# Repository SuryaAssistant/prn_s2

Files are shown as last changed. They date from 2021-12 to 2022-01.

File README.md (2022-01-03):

<!-- Title -->
<span align = "center">

# PRN
  <b>Bidirectional SMPS Inverter</b>

STM32 Code

September - December 2021

This repository is open to copy for Educational purpose only and not for commercial use

</span>
<!-- End of Title -->

## Warning
The code and OpenHantek software are produced in Linux OS computer. We recommend you to use or edit the code in Linux computer for compatibility purpose. Nevertheless, you still can use this repo in Windows computer with some configuration but not for OpenHantek.

## Brief Overview of The Repository
This repository is used to save and documenting the development of bidirectional SMPS inverter project. The project was took place in Instrumentation and Control Laboratory, Universitas Sebelas Maret.

## Prequerities
Yout need to have this software before use this repository
- STM32CubeIDE v1.6.1 or above. Link : https://www.st.com/en/development-tools/stm32cubeide.html
- OpenHantek6022 (Linux). Link : https://github.com/OpenHantek/OpenHantek6022
- Autodesk Eagle v9.3.0 or above (Linux or Windows). Link : https://www.autodesk.com/products/eagle/free-download

## How To Use (Linux)
From Terminal, clone this repository to your folder
```
git clone https://github.com/SuryaAssistant/prn_s2
```

Open STM32CubeIDE and then open project `prn_s2.ioc` in `stm32` folder.

The main code is saved in `stm32/Core/Src/main.c`.

## How To Use (Windows)
Download this repository by clicking green button in right-top of repository.

Extract the zip file and then move the `stm32` folder into <b>STM32CubeIDE workspace</b> in (usually) `C:\Users\{Your_Computer_Name}\STM32CubeIDE\{Your_Workspace_Name}\`.

## Clock Configuration
<span align="center">
  
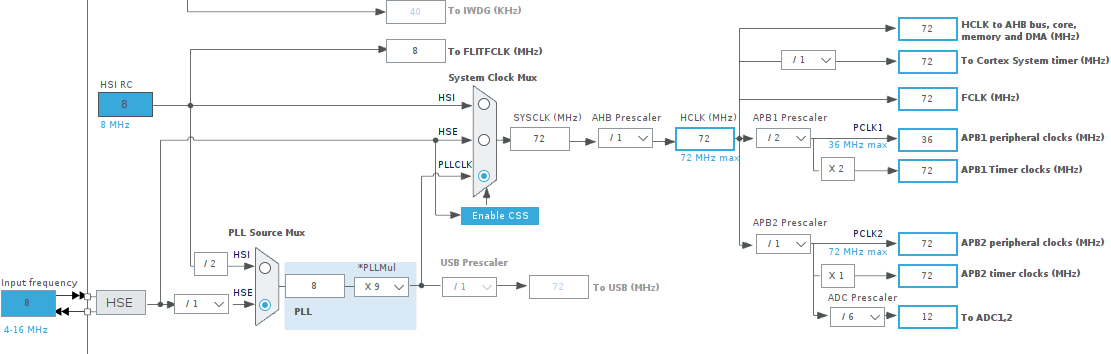
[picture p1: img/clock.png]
 
  
</span>

## Pinout
<span align="center">
  
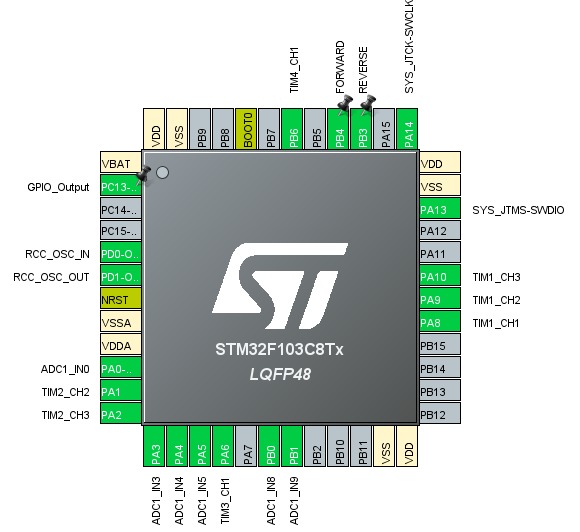
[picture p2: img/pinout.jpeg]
 
  
</span>

## Further Information
- Read the STM32CubeIDE timer and ADC configuration in https://github.com/SuryaAssistant/prn_s2/tree/main/tutorial
- Read SPWM specific configuration in https://github.com/SuryaAssistant/prn_s2/tree/main/spwm
- PCB schematic and board Design Documentation in https://github.com/SuryaAssistant/prn_s2/tree/main/pcb

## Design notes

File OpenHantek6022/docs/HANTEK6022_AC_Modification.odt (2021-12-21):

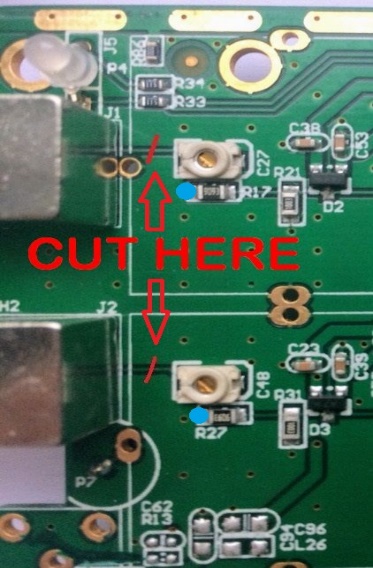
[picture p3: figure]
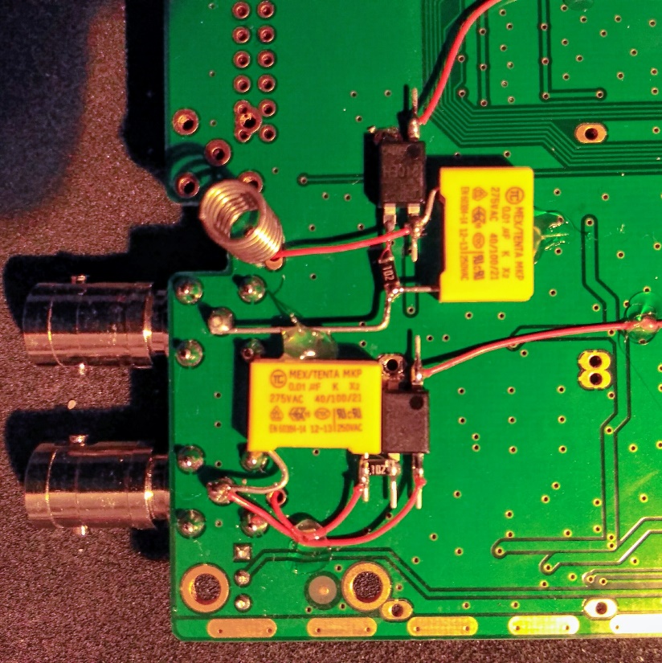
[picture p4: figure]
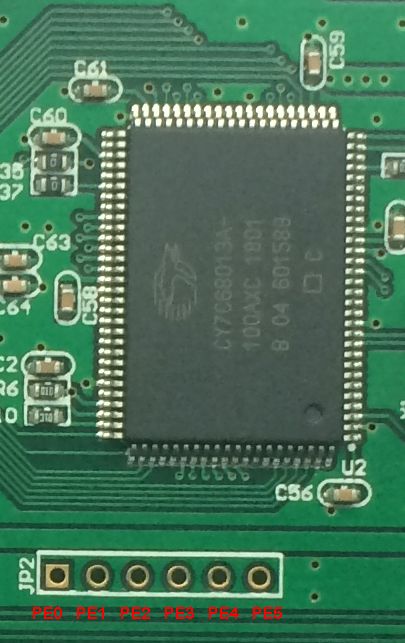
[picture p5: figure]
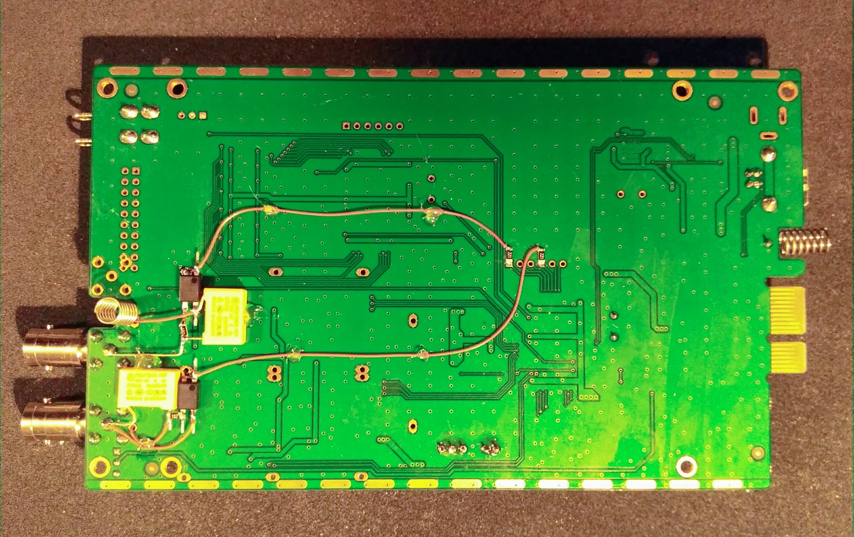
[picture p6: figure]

# Modification of HANTEK 6022BE to provide AC/DC coupling of the inputs

A big issue of the Hantek scope is the missing AC coupling (see front end schematics below).

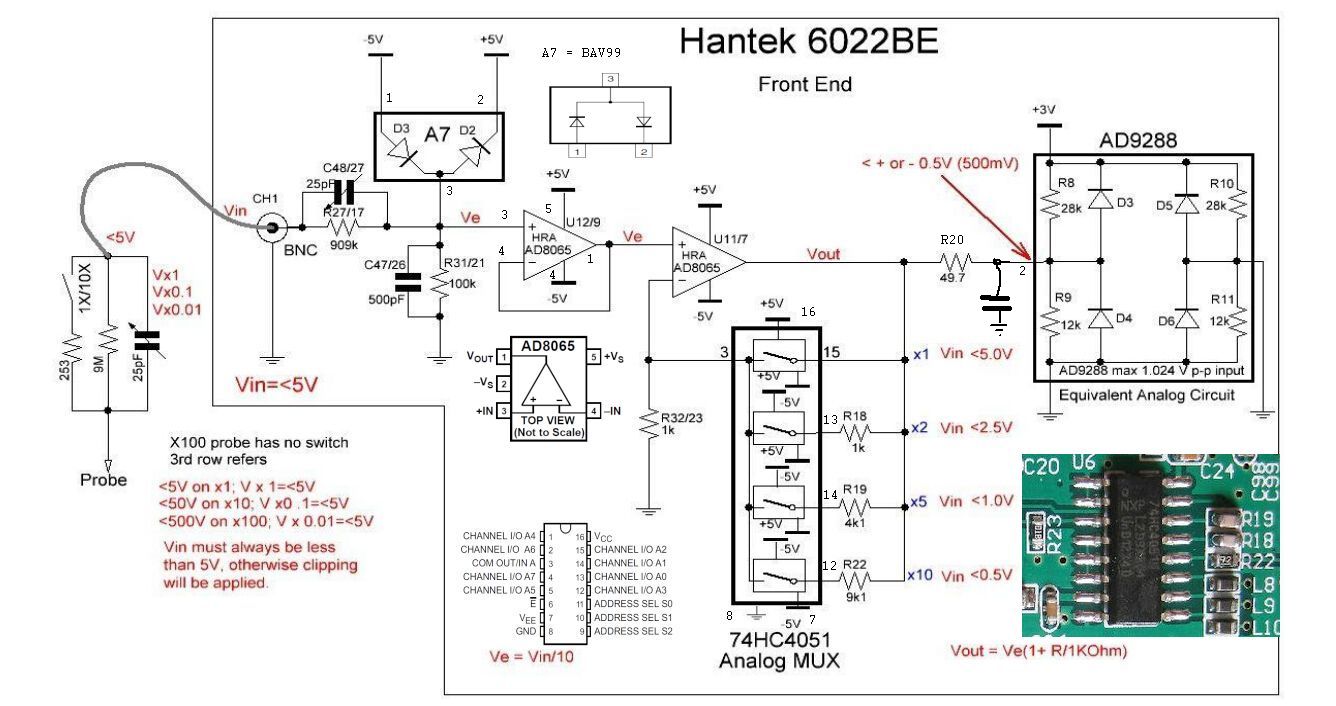
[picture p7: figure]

This document shows a simple hardware modification similar to the SainSmart DDS120 scope.
(HW info: https://sigrok.org/wiki/SainSmart_DDS120)

1. Cut the traces between BNCs and R17/R27 and add a 100nF capacitor across. This gives an AC coupling with cut-off frequency fc = 1.6 Hz. (10nF in the prototype gave fc = 16Hz with a visibly tilted 1kHz square wave.)
2. To select DC short the capacitor by a PhotoMOS AQY210EH. The 1K0 resistor limits the current when the PhotoMOS shorts the 100 nF capacitor.

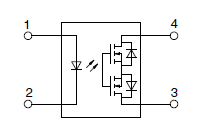
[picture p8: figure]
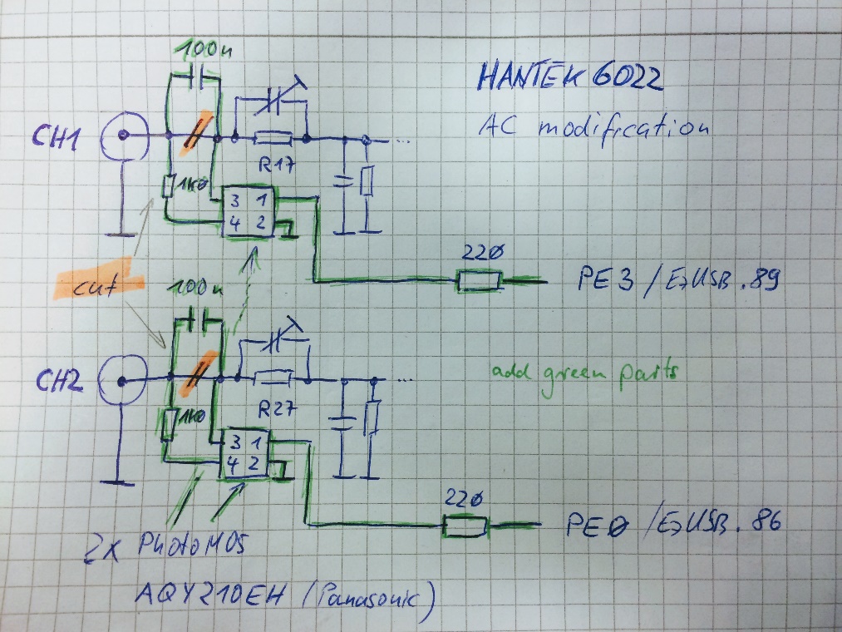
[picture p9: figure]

3. JP2 next to the EzUSB chip delivers the signals PE0 .. PE5. PE0 (CH2) and PE3 (CH1) are used, same as in SainSmart DDS120 (red arrows).
4. All new components are soldered/glued on the bottom side of the PCB.
5. One wire per channel (blue arrow) connects to R17/R27 on the top side (blue dot).

OpenHantek6022 supports this AC modification starting with version v2.17-rc6 / FW0204.
To enable this feature go to the directory build and type

cmake -D HANTEK_AC=1 ../
make -j2

Later OpenHantek6022 versions beginning with 3.1.1 offer an Oscilloscope/Settings option that allows you to use the modification without the need to compile your own version.

### Hantek DSO-6022BL

The DSO-6022BL doesn't provide JP2. PR #9 implemented a change to use R40 (PE0, CH2) and R41 (PE1, CH1) connected to USB-XI port as connections for the AC/DC modification that are easier to solder than the pins of the EzUSB chip.

This change is available starting with FW0208.

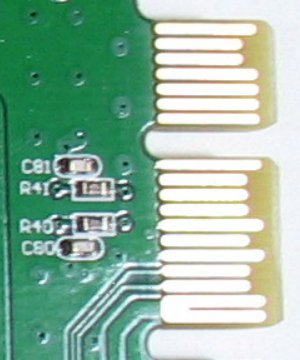
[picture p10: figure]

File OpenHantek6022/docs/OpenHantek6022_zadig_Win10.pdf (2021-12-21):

# Hantek 6022BE -zadig’s driver installation in Windows 10.1909 64 bit

1. Ensure the oscilloscope device has no driver attached:

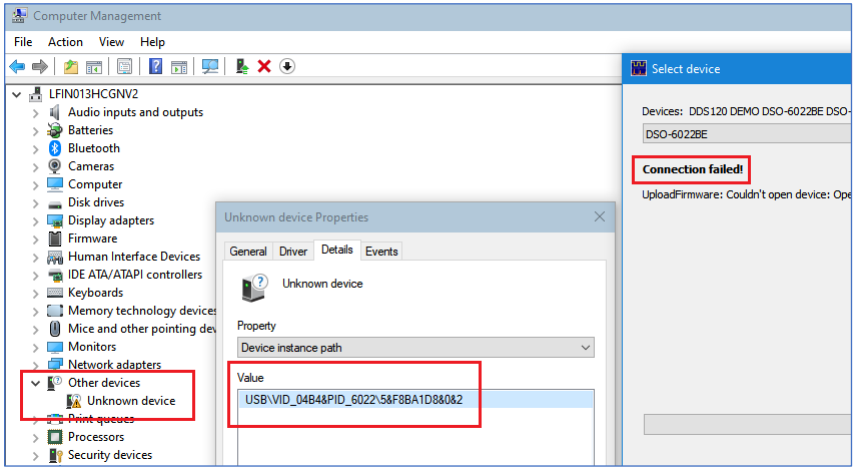
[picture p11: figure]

a. If it has, from Device Manager select Driver -> Uninstall device -> check “Delete the driver software for this device” -> Uninstall -> disconnect and reconnect the oscilloscope -> repeat if any other driver is still found
i. Once my Windows 10 (1909x64) refused to delete the driver from Device Manager (it always came back upon reconnection), but it did from Windows 10 -> Settings -> Devices -> Bluetooth & other devices -> “Your Device” -> Remove device (here I didn’t have any “Delete driver” but then Windows “forgot” the driver so probably removed it successfully):

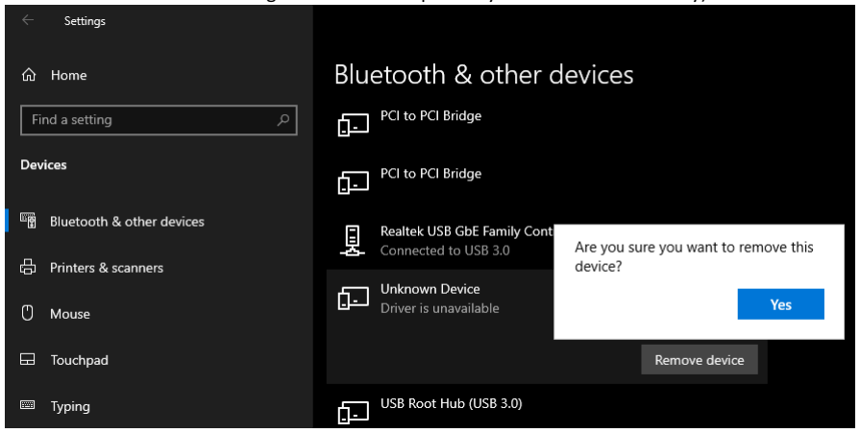
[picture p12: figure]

2. If you start “OpenHantek.exe” should tell you that “Connection failed!” message. Ignore it for now, you are on stage 0 (04B4/6022 device with no driver).

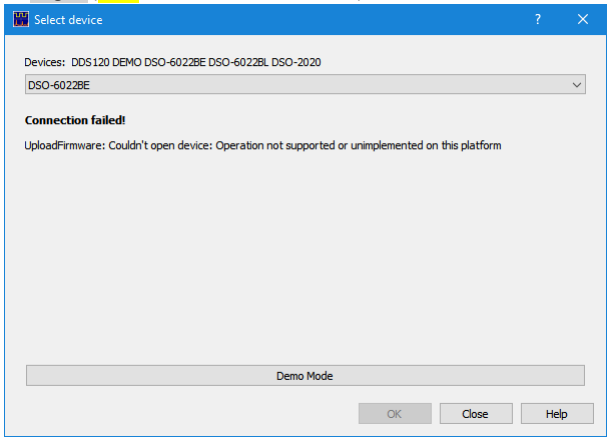
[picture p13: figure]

3. Start “zadig-2.5.exe”
a. If the device has no driver should be picked up automatically:

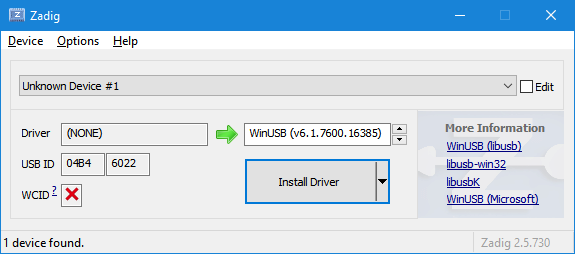
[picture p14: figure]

i. If it’s not, then try from menu Options->List All Devices and choose your 04B4/6022 device
b. Select Install Driver and wait around 1 minute:

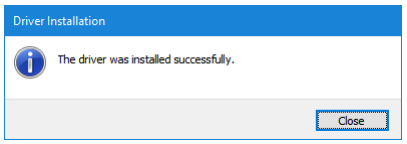
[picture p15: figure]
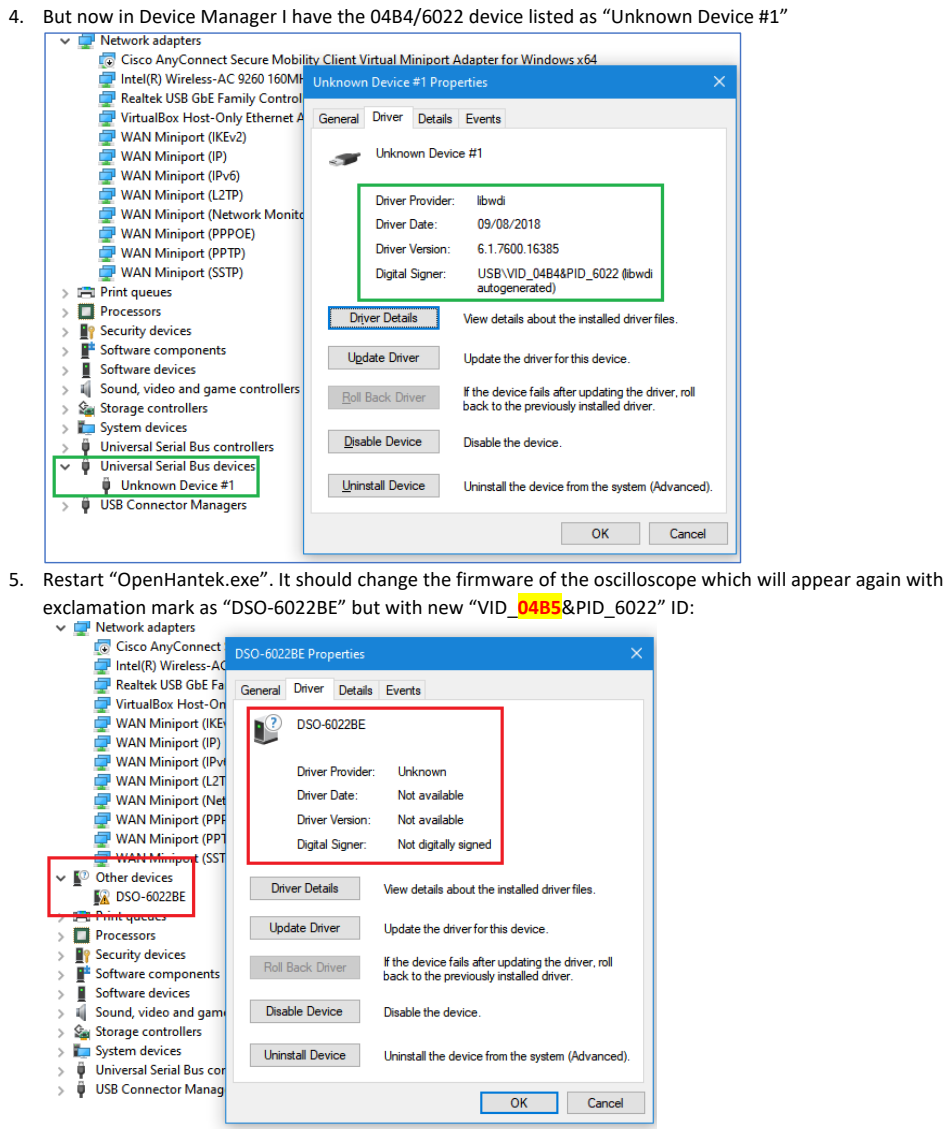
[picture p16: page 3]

4. But now in Device Manager I have the 04B4/6022 device listed as “Unknown Device #1”
5. Restart “OpenHantek.exe”. It should change the firmware of the oscilloscope which will appear again with exclamation mark as “DSO-6022BE” but with new “VID_04B5&PID_6022” ID:

6. Note: “OpenHantek.exe” should still tell you the “Connection failed!” message. Ignore it again, you are on stage 1 (04B4/6022 device with driver but 04B5/6022 device with no driver).

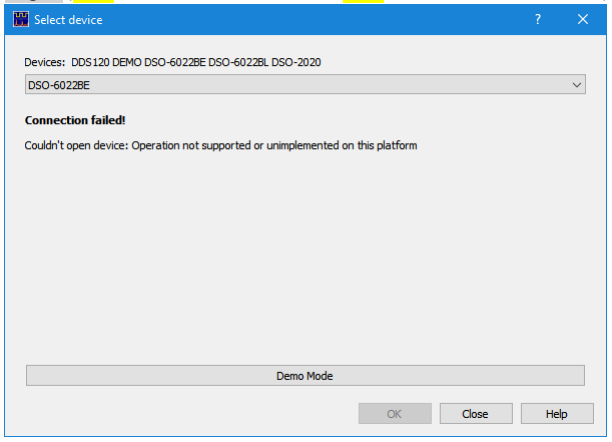
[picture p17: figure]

7. Start “zadig-2.5.exe” again!
a. If the device has no driver should be picked up again automatically:

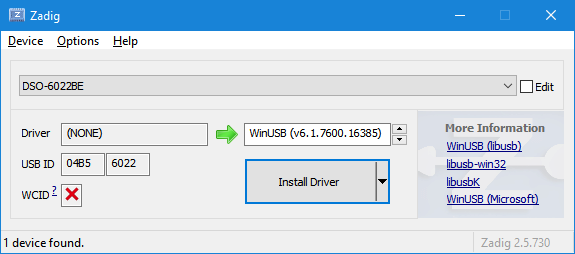
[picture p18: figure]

i. If it’s not, then try from menu Options->List All Devices and choose your 04B5/6022 device
b. Select Install Driver and wait around 1 minute:

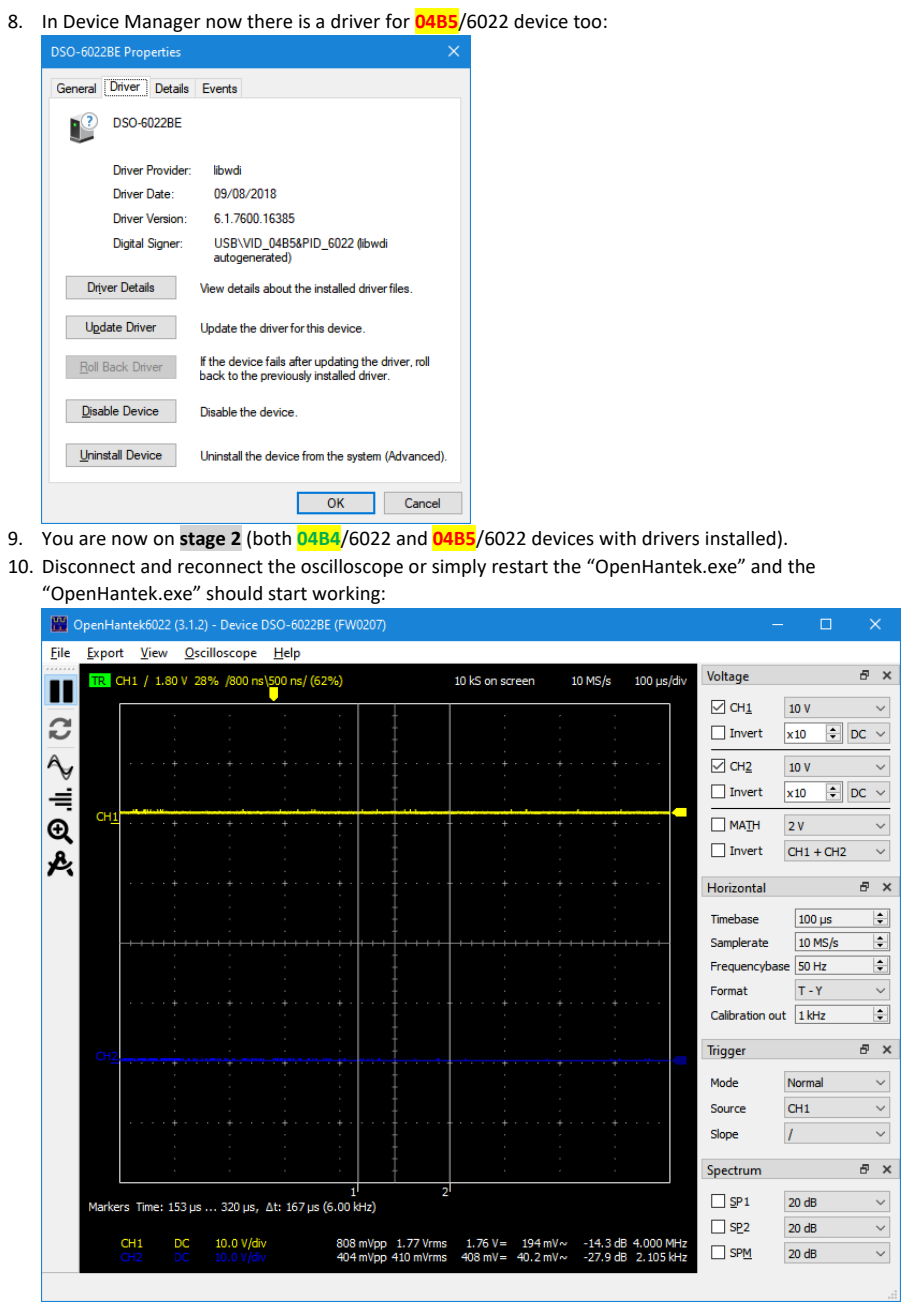
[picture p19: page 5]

8. In Device Manager now there is a driver for 04B5/6022 device too:
9. You are now on stage 2 (both 04B4/6022 and 04B5/6022 devices with drivers installed).
10. Disconnect and reconnect the oscilloscope or simply restart the “OpenHantek.exe” and the “OpenHantek.exe” should start working:

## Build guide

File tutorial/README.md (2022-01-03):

<!-- Title -->
<span align = "center">

# PRN
  <b>ADC & Timer Configuration </b>

</span>
<!-- End of Title -->

### ADC Configuration
In this configuration, choose `ADC1` and check the ADC pin as below

| ADC PIN | Nomor Channel|
|---|---|
| IN0 | 0 |
| IN3 | 1 |
| IN4 | 2 |
| IN5 | 3 |
| IN8 | 4 |
| IN9 | 5 |

In the parameter setting, set as picture below

<span align="center">
  
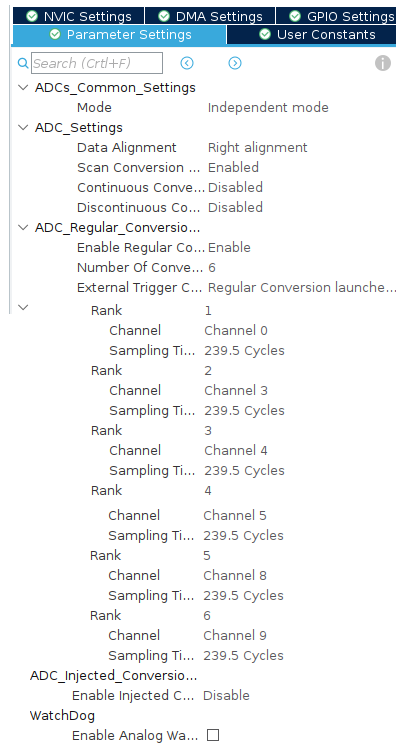
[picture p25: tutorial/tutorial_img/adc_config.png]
 
  
</span>

Open DMA Setting and click `Add` to add ADC1 into DMA Setting.

Set DMA Mode as Circular and set `Data Width` as `Word` both in peripheral and memory column.

<span align="center">
  
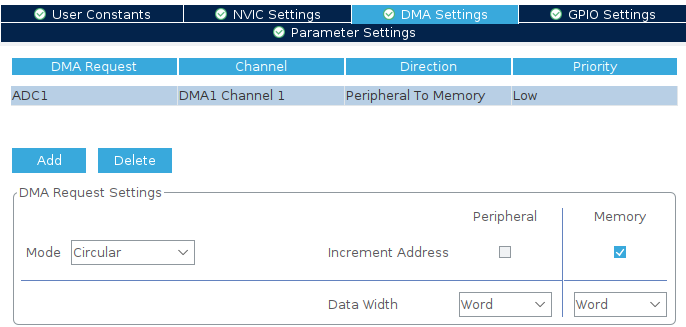
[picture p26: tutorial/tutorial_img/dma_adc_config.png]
 
  
</span>

### Timer Configuration
For the timer configuration, set all timer's clock source as internal clock.

This Repository use 4 timer with different PWM frequency for all Timer.
The frequency is set by changing the prescaler and counter in every Timer.

| Timer | Prescaler | Counter | Frequency |
|---|---|---|---|
| TIM1 | 10-1 | 144 | 50 kHz |
| TIM2 | 8-1 | 600 | |
| TIM3 | 10-1 | 288 | 25 kHz |
| TIM4 | 72-1 | 2000 | 1 kHz |

Set the timer configuration as same as configuration in the table below.
For the Channel, set channel as `PWM Generation CHx`.

| Timer | Channel | Polarity |
|---|---|---|
| TIM1 | CH1 | LOW |
| TIM1 | CH2 | LOW |
| TIM1 | CH3 | HIGH |
| TIM2 | CH2 | LOW |
| TIM2 | CH3 | LOW |
| TIM3 | CH1 | LOW |
| TIM4 | CH1 | LOW |

### Frequency Calculation
```
Counter frequency = (required frequency * counter period)

Counter period = counter frequency / required frequency
```

```
Prescaler = (clock frequency / counter frequency) - 1
```

For example, maybe you need 25 kHz frequency. 
Let we say the counter frequency is 7.2 Mhz (you can change it as you want, but 7.2 will give easy calculation).
The counter period will be :

	counter period = 7.2Mhz / 25kHz
	counter period = 144

Then, calculate the prescaler

	prescaler = (72MHz / 7.2MHz) - 1
	prescaler = 10-1

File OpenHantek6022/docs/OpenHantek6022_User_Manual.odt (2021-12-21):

OpenHantek6022 User Manual

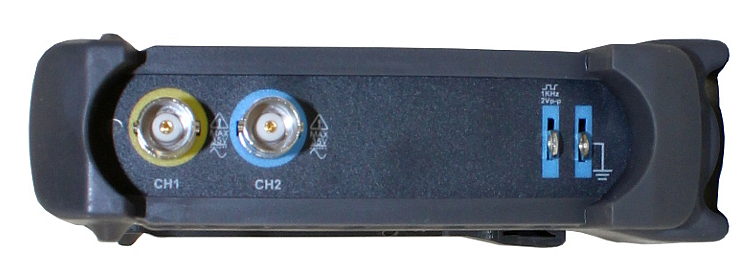
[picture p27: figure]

The digital storage scope Hantek6022BE (as well as the similar Hantek 6022BL) allows to measure two voltage channels CH1 (yellow) and CH2 (blue).

The input impedance is 1 MΩ || 25 pF (a typical value for scope inputs).

The measurable input signal range is ±5 V.

Input voltages outside the safe range of ± 35 V can lead to permanent damage!

The calibration output (blue, right side) delivers a square wave 0 V / 2 V @ 1 kHz that can be used to adjust the frequency compensation of 10X probes.

The frequency can be varied between 32 Hz and 100 kHz to deliver a versatile test signal.

Each input section contains an 8-bit ADC (analog to digital converter) that allows to sample the input voltage at a chosen sampling rate (10 kS/s ... 30 MS/s) and to transfer the digital value to the PC via USB where it will be processed and displayed.

The Hantek6022 uses USB 2.0 high-speed transfer. It must be connected directly to the PC without an USB hub in between. Make sure that the device does not share its high-speed bus with other devices, this can be checked with the Linux commands lsusb; lsusb -t.

The device is powered over USB with a typical current consumption of less than 500 mA, so a good quality USB 2.0 cable is sufficient, no need to use the strange red/black Y-cable.

The program OpenHantek6022 allows the usage of the scope under the Linux operating system. The development and test platform is Debian stable.

OpenHantek6022 requires a recent Linux system with libusb-1.0, libfftw3 and the Qt libraries.
It compiles also under RPi, FreeBSD, MacOS and Windows, but these systems are untested.

Fork me on GitHub! https://github.com/OpenHantek/OpenHantek6022

This document describes program version 3.2.5, subject to change without notice.

# Starting OpenHantek6022

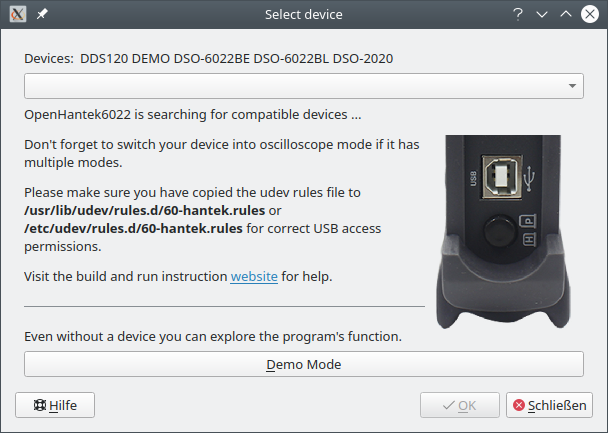
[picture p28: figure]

The executable program is named OpenHantek. It is installed (under Linux) in the directory /usr/bin, so it can be called directly from a terminal or via the menu entry OpenHantek.

The hardware of Hantek DSO6022 contain a Cypress EzUSB processor that controls the data sampling and the USB transfer. The device does not contain a flash, the firmware must be loaded into the RAM at the 1st program start after powering the device. The uploaded firmware is lost after switching off the scope or disconnecting the USB, so the device can never be bricked.

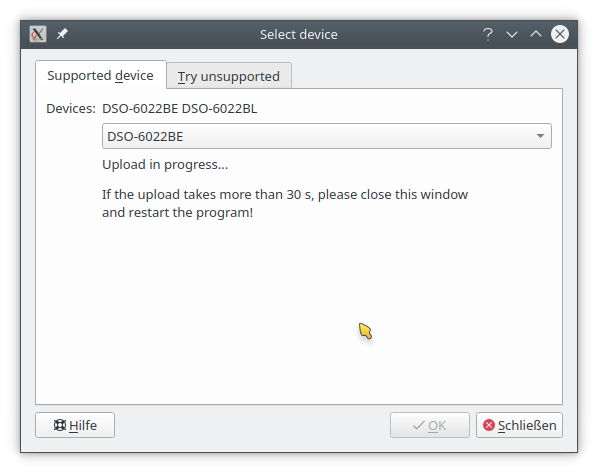
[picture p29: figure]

After starting the program, it searches for a supported device by checking the USB VID/PID of all connected USB devices.

DSO-6022BE: VID 0x04B4 PID 0x6022

DSO-6022BL: VID 0x04B4 PID 0x602A

DSO-2020: VID 0x04B4 PID 0x2020
DDS120: VID 0x8102 PID 0x8102

If only one scope is found, the firmware will be uploaded automatically. In case of more devices the user can select from the list of devices.
After the upload the VID changes to 0x04B5. The PID of the DSO-6022BE/BL doesn't change.

The DSO-2020 changes its PID to 0x6022 and
the DDS120 changes its PID to 0x0120.

If the firmware is uploaded successfully, the LED left of the CH1 connector blinks red.

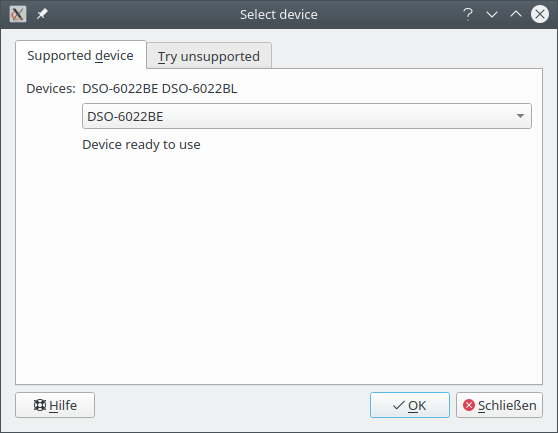
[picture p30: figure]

If the upload takes more than 30 s, please close the window and restart the program.

This can happen in rare cases when another high speed USB device blocks the same USB bus.

If this happens, use another USB port of the computer or disconnect the other device.

The oscilloscope shall be connected to an HS-USB bus alone so that it works undisturbed and also does not interfere with other devices.

Under Linux you can check this with:
lsusb; lsusb -t

If the device is ready to use, the scope program starts automatically.

Follow the Quick Start Guide to get a feeling for the program or start your real measuring job.

# Demo Mode

You can explore the look and feel of the program even without having the scope hardware available, just click the Demo Mode button on the Select device window
or start the program as: OpenHantek --demoMode

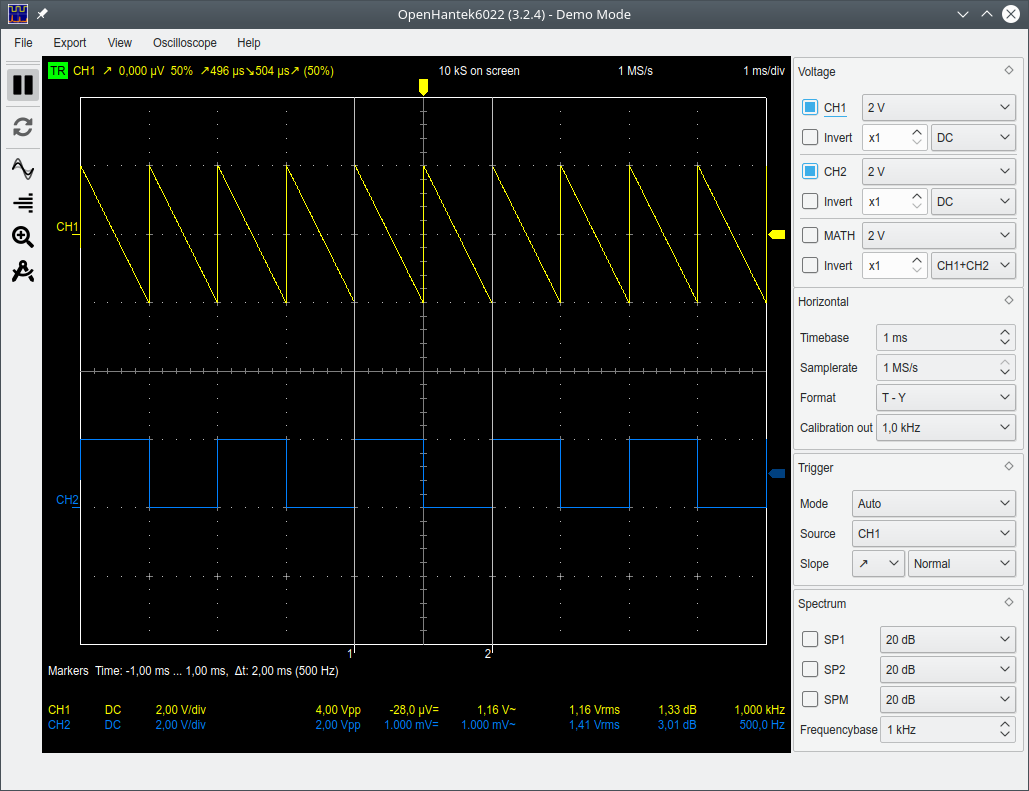
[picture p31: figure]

OpenHantek with default Linux theme „Breeze“

This demo mode provides a sawtooth and a square voltage. You can play with gain, timebase and trigger settings, check out the spectrum of the signals or export the data as *.csv, *.json, *.pdf or *.png file.

# Quick Start Guide

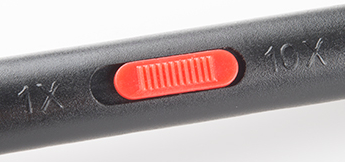
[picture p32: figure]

# Use one of the two supplied probes and connect it to CH1.

# Switch the red slider on the probe into the 1X position.

# Connect the hook of the probe tip to the left calibration out connector.

# Connect the alligator clamp of the probe to the right calibration out connector.

# The scope will show a yellow square wave trace.

# If the trace isn't stable drag the small yellow arrow on the right of the trace a little bit up, so that it is positioned in the middle of the trace.

# The trace will snap into position and the top left red TR will turn into green TR .

# Play a little with the settings to gain experience. Detailed descriptions of all features can be found on the following pages.

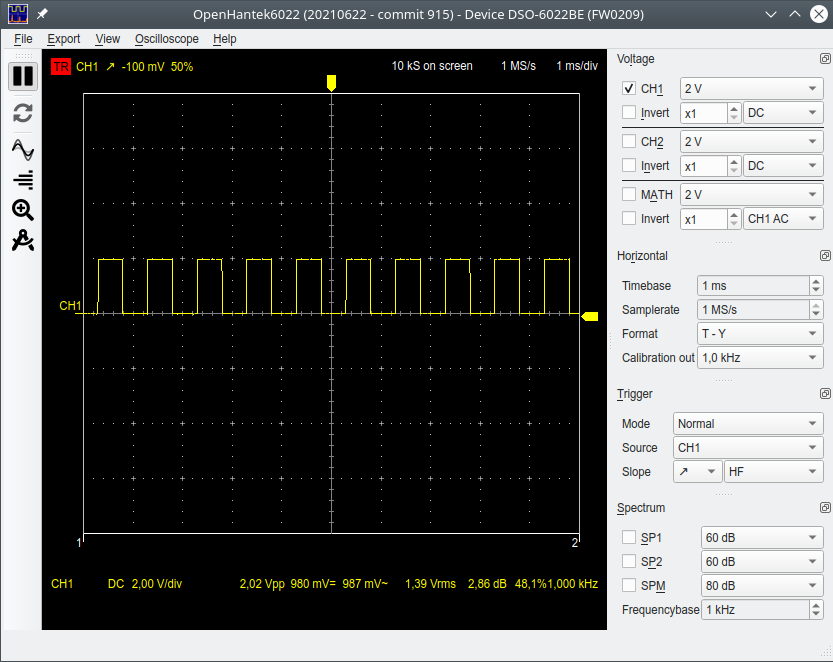
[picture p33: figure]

# OpenHantek with Linux theme „Fusion“ that gives a more compact screen

# Using OpenHantek6022

The OpenHantek6022 program resembles the typical view of a real hardware oscilloscope, so anyone who has experience with scopes (including analog CRT devices) should be able to operate it.

Those who lack this experience should keep in mind that a scope is a complex measuring instrument, so a basic understanding of how it works is required to perform correct measurements.

The program version, device type and firmware version are displayed in the top line of the window (marked green). This information is mandatory when reporting issues.

The scope functions can be controlled by the four docks (marked orange) on the right: Voltage, Horizontal, Trigger and Spectrum. These docks can be floated, rearranged or tabbed by grabbing their title lines, dragging and dropping. Drop on the screen to float it or move it over the docking area and drop it either on an empty blue space to rearrange it or drop it on another blue dock to tab both together. This way you can reduce the needed screen height when used on older computers or laptops.

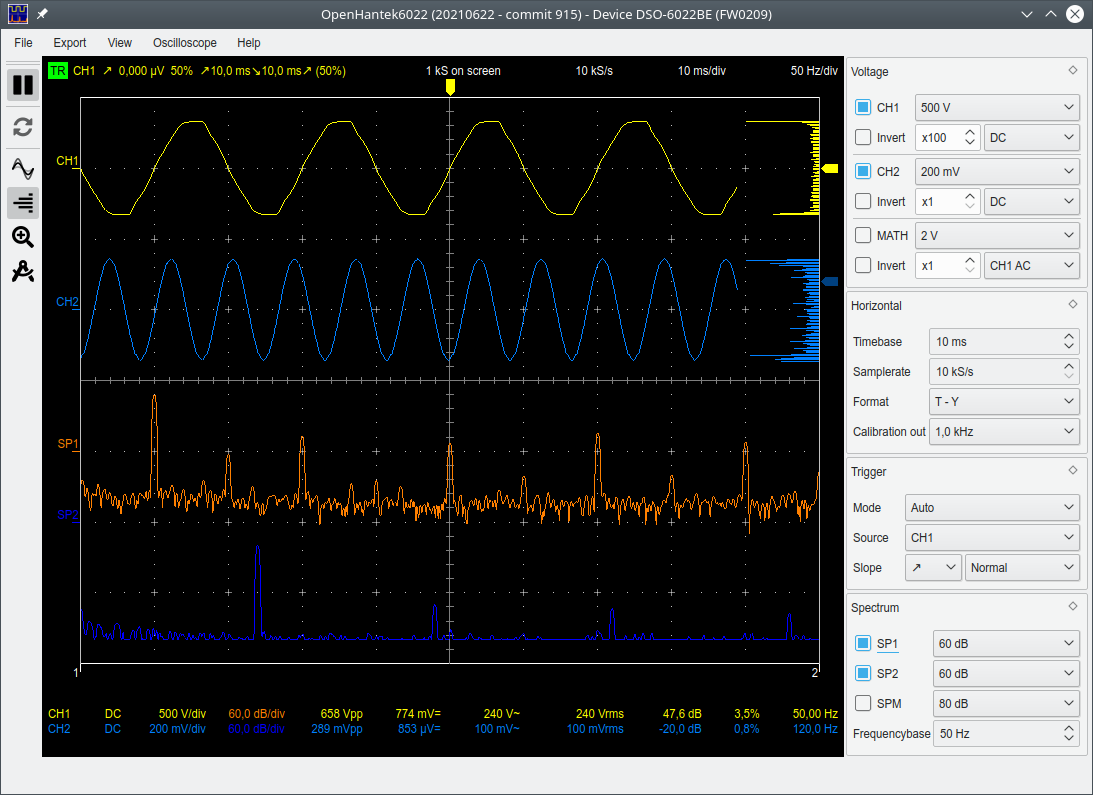
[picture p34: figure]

The selected settings are automatically saved when you exit and restored the next time you start the program.

The bottom line shows settings and results of measurement and calculation.

## Voltage

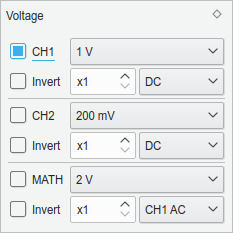
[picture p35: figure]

Both channels measure the voltage related to GND.

GND is directly connected also to the PC and to the main's GND so never ever connect GND of the scope to other voltages as it can destroy the scope and the PC!

This is not a limitation of this device but typical for most scopes, even for much more expensive ones.

Each channel can be selected or deselected by ticking CH1 or CH2. Input signal polarity can be Inverted.

AC/DC coupling can be selected if the scope's HW supports this feature (→ Help menu entry AC Modification).

The vertical position of the trace can be changed by dragging the name label left of the trace.

The default colors of the traces CH1 and CH2 correspond to the channel colors yellow and blue on the front of the scope hardware.

The maximum measurable input signal range is -5 V … +5 V, values outside this range are clipped (shown as minimum or maximum value).

Input voltages outside the safe range of ±35 V can lead to permanent damage!

Each channel has an amplifier with selectable gain that allows the amplification of the input signal by the factor 1X, 2X, 5X or 10X, the available input voltage range decreases accordingly from ±5 V to ±2.5 V, ±1 V and ±500 mV.

Input sensitivity per division can be selected from 20 mV/div up to 5 V/div (1/2/5 steps) by the control field, e.g. 2 V.

The display's height is 8 div, marked with horizontal dotted lines on the screen.

The two supplied Hantek probes allow a signal attenuation of 1/10, so the possible maximum input voltage range is increased ten times to ±50 V (e.g. 12 V input will be measured by the scope as 1.2 V). The probe attenuation box eases the usage of this x10 range by multiplying the displayed value by 10 (the measured example value of 1.2 V from above will be displayed correctly as 12 V). To support a variety of different probes, you can type in any attenuation factor 1..1000 or simply scroll up/down.

The MATH channel (purple color) allows simple calculations with measured signals:

- CH1+CH2, CH1-CH2, CH2-CH1, CH1*CH2, CH1 AC, CH2 AC

The subtract functions allow the measurement of voltages between two points in a circuit by measuring both with CH1 and CH2 and subtracting the values.

Math mode CH1*CH2 can be used to calculate the momentary power as product of voltage and current (when current is measured with a 1 Ω shunt in the GND line then 1 V in MATH display equates a power of 1 W). Or you can use a current probe and scale accordingly.

The AC modes calculate the AC component of a channel by averaging over the sampled signal and subtracting this value from the samples, leaving only AC.

The scope also calculates typical values of each active channel and displays them in the colored bottom lines, the values from left to right are:

Channel name, AC/DC coupling or math mode, voltage range, spectrum range,
peak-to-peak voltage (Vpp), DC voltage component, AC voltage component, true RMS voltage ( i.e. sqrt( DC² + AC² ) ), RMS displayed as dB, power dissipation on a defined load (optional, load resistance can be set in Oscilloscope/Settings/Analysis), the THD of the signal (optional, can be enabled in Oscilloscope/Settings/Analysis) and finally the signal frequency.

A red channel marking (e.g. CH1) warns when the input signal exceeds the channel's physical input range and clipping has occurred.

## Horizontal

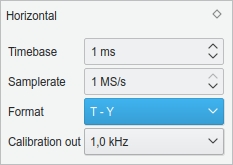
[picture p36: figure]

The displayed time range of the trace can be selected by Timebase between 10 ns/div and 100 ms/div in 1/2/5 steps. The display's width is 10 div, marked with vertical dotted lines on the screen.

The optimal Samplerate will be selected automatically but the user can also change this manually within the realistic range. The maximum sample rate is 15 MS/s when sampling two channels.

If only CH1 is used, the maximum sample rate doubles to 30 MS/s.

The effective sample size used for display, calculations and export is always 20 kS. For (effective) sample rates lower or equal 10 MS/s a 2 to 200 times oversampling is used, i.e. to get 20 kS @ 1 MS/s the scope samples 200 kS @ 10 MS/s and averages over 10 samples each to decrease the noise floor by 10..20 dB. This increase the effective resolution of the 8-bit ADC to almost 10..12 bit at low speed operation.

(Each 4X oversampling adds one bit, 4X → 9 bit, 16X→10 bit, 64X→11 bit, 256x → 12 bit…).

→ https://www.silabs.com/documents/public/application-notes/an118.pdf

An overview of all settings is also visible top right of the trace window.

Format selects T-Y (i.e. normal scope display, voltage (Y) over time (X))
or X-Y (CH1 = X, CH2 = Y), the horizontal position on the screen can be changed by dragging the trigger marker on the top, the vertical position on the screen can be changed by dragging channel CH2 left of the traces window.

Calibration out selects the frequency of the calibration output (a 2 Vpp square wave) on the right of the scope, set to 1 kHz at each program start. The frequency can be selected between 50 Hz .. 100 kHz in 1/2/5 steps. This can be used as a simple signal generator. The output signal is created by software, so at high frequencies a phase jitter may occur (±250ns).

Two Markers (vertical lines, marked with 1 and 2) allow to measure time as well as frequency of the traces by dragging the lines. New markers can be positioned also by click and drag inside the trace window. <Double click> creates two markers with a distance of 10% of the screen width, allowing a 10x zoom. <Control> decreases the distance to 1% → 100x zoom, <Shift> centers the markers around the trigger position. Both modifiers can be combined.
<Right double click> moves the markers out of the way to the left and right screen margins.

<Scroll wheel> moves both markers left/right, <Ctrl scroll wheel> changes their distance.

- The digital Phosphor function (sine waves icon) simulates a slow fade out of traces to detect short events (shortcut <P>).

- The Histogram (gaussian bell icon) shows the probability density function of the signal voltage at the right to identify hidden structures of the signal. (<H>).

- The Zoom function (magnifying glass icon) displays a new window below the main window with zoomed time range equating the markers distance (<Z>).

- The Measure function (drafting compass icon) opens an extra section and allows measurement of time or frequency span and levels (<M>).

## Trigger

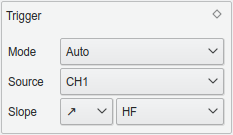
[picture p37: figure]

Triggering allows to display a stationary trace by fixing a rising or falling Slope of the signal of the selected Source channel to a defined position on the screen. The triggering is done in software by searching for the trigger condition in the sampled values and skipping the necessary amount of leading samples to position the trace accordingly.

Trigger Mode can be:

- Roll - display a free running trace (useful for slow timebases - due to the omission of the software triggering the display is refreshed permanently in real-time)
- Auto - display a running trace even if no trigger point is detected
- Normal - display no trace without active trigger, hold the last triggered trace
- Single - display a new triggered trace every time the space bar is pressed

The play/pause icon (top left) starts and stops the display during Auto and Normal mode.

The keyboard shortcuts <Spacebar> or <Pause> or the key <S> also work as Start / Stop.
If the <Spacebar> does not work under Windows, you should use the other alternatives.

The refresh icon (key <R>) clears the screen and starts a new trace in roll mode.

Trigger Source can be CH1 or CH2

Trigger Slope:

- ↗ Triggers on rising slope
- ↘ Triggers on falling slope
- ⤨ Triggers alternatively on rising and falling slope

Trigger setting can be HF (trigger even on fast spikes or glitches), Normal or LF (trigger on „stable“ slope only, ignore fast spikes).

The trigger level (voltage) can be selected by dragging the small colored (e.g. yellow) arrow to the right of the recording window. The trigger position on the screen can be selected by dragging the colored (e.g. yellow) arrow at the top of the window.

Trigger status (TR = triggered, TR = not triggered), source, slope, voltage level and horizontal position are displayed in the upper left corner of the trace window followed by the pulse width of the triggered pulse and the following pulse in opposite direction and the duty cycle.

Trigger Slope ⤨:
Triggers on alternating slopes. Can be used together with digital phosphor to show a kind of eye diagram, either triggered on the signal itself or by a stable trigger signal
on the other scope channel.

### Spectrum

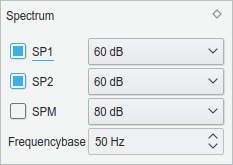
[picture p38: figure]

The program calculates the voltage spectrum of the three channels using the discrete FFT and displays the results if enabled.

The displayed values are shown as dBV (0 dBV equals 1 V rms) or based on another reference level, see below.
The Frequencybase setting selects the resolution of the spectrum in Hz/div.

The applied Window function as well as the reference level for the spectrum calculation can be changed in the menu: Oscilloscope / Settings / Analysis

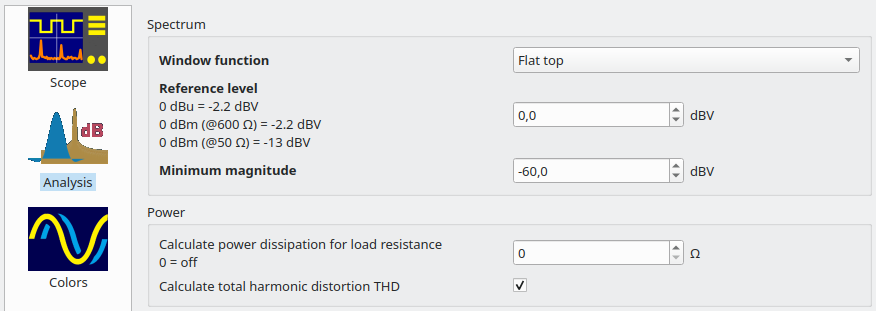
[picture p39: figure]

Typical window functions are Hann (raised cosine), Gauss or Flat top. The Hann window has the best frequency selectivity (narrowest bandwidth) while the Flat top window allows accurate amplitude measurements. Gauss window characteristic is in between.

The Flat top window is typically employed on data where frequency peaks are distinct and well separated from each other (e.g. for harmonic distortion measurements).

If the frequency peaks are not guaranteed to be well separated, the Hann window is preferred because it is less likely to cause individual peaks to be lost in the spectrum.

Other different window functions are available for the curious user.

The frequency range of the spectrum can be selected in the Horizontal section, minimum frequency is always zero, the maximum frequency is limited to the Nyquist frequency, this is half the sampling rate.

A lower sampling rate yields a narrower frequency lobe and increases the selectivity while a higher sampling rate allows to display a wider frequency range at the cost of less selectivity.

Important: Sampling a signal with spectral components above the Nyquist frequency leads to aliasing, i.e. the higher spectral components are mirrored into the low frequency range.

This is not a limitation of this device, but should be considered when looking at the spectrum.

The default Reference level of 0 dBV converts a 1 V rms sinusoidal signal into a displayed
0 dB amplitude frequency peak.
Professional audio measurements typically use dBu (aka. dBm @ 600 Ω load):
0 dBu = 0 dBm = 0.775 V rms which corresponds to a reference level of -2.2 dBV.
Conversely, for RF with a 50 Ω load, 0 dBm equates approximately 0.224 volts:
0 dBm = 0.224 V corresponds to a reference level of -13 dBV.
The Minimum magnitude setting hides the noise floor and calms the display;
all spectral components below this level are not displayed.
The Power setting allows to define a (dummy) load resistance of 1..1000 Ω for which the power dissipation of the measured voltages is determined ( R = 0 disables the calculation).
Also the THD of the signal can be shown optionally (only useful for harmonic signals).
Calculation: THD = sqrt( power of all harmonics / power of fundamental )

### Zoom Function

# The zoom function (magnifying glass icon, shortcut key <Z>) opens a second window below the main window with an enlarged time range corresponding to the distance between the markers (1 & 2).

# New markers can be positioned by click and drag inside the (un-zoomed) trace window.

# A <double click> (left) creates two markers close to each other with a distance of 10% of the screen width, thus defining a zoom rate of 10, <ctrl double click> defines zoom = 100.

# The shift modifier centres the markers around the trigger point.

# The <scroll wheel> moves both markers left / right, <ctrl scroll wheel> changes their distance.

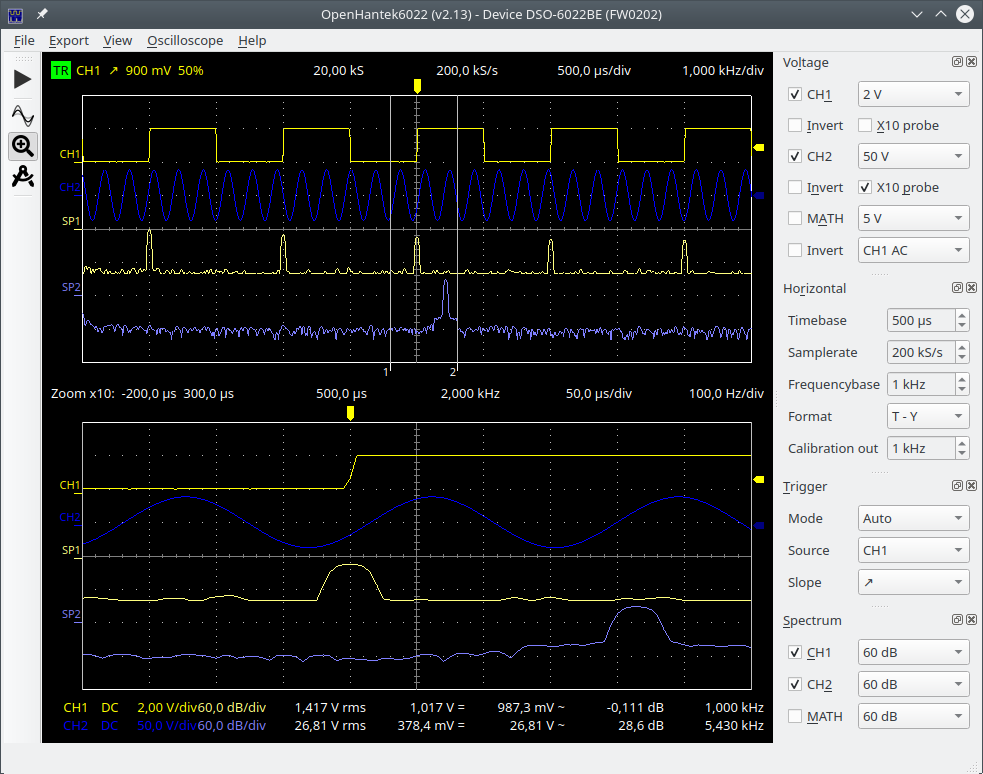
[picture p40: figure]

### Cursor Measurements

The measurement function (drafting compass icon, shortcut <M>) allows to measure voltage or spectral amplitude as well as time or frequency intervals of one or more displayed tracks.

Select the trace (e.g. SP1), set it to ON (clicking on the ON/OFF text toggles its state) and draw a (yellow) rectangle (red circle) to measure e.g. frequency and magnitude difference.

You can also draw another (blue) rectangle (purple circle) to measure a different trace.

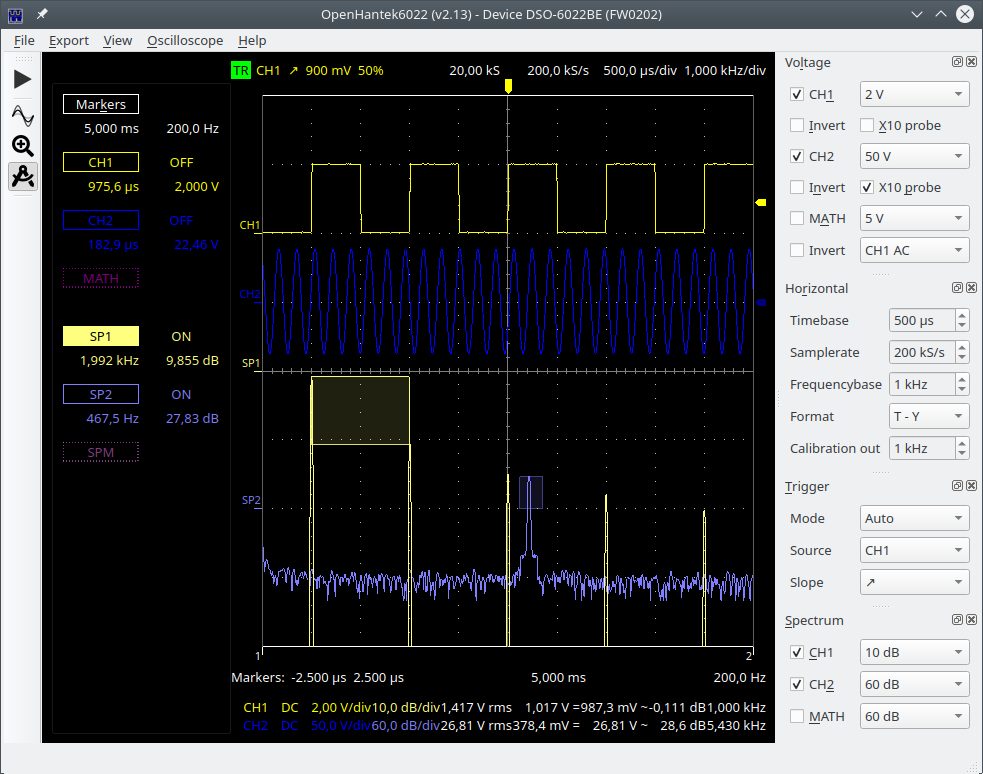
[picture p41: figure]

### Settings

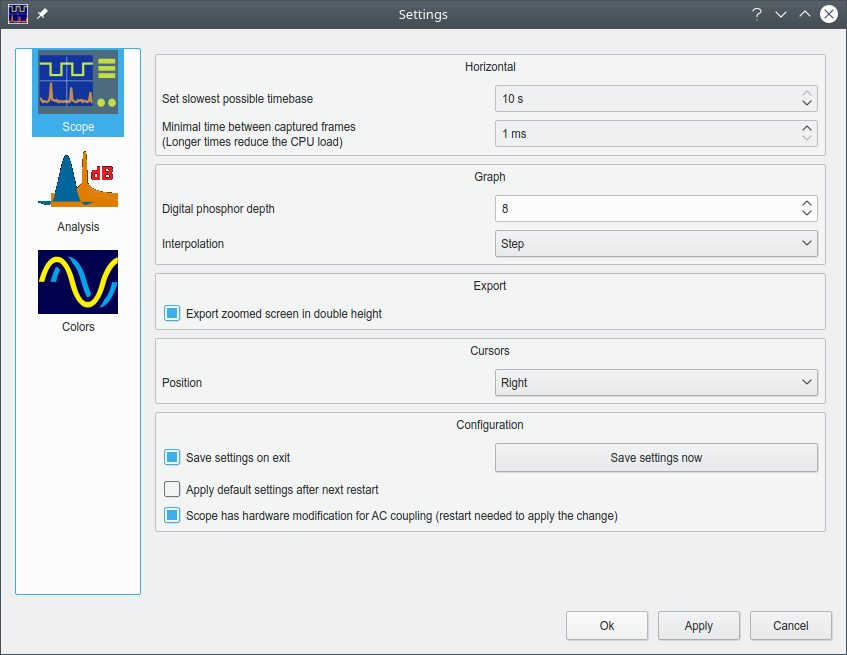
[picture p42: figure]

## The program behaviour can be chosen in Oscilloscope / Settings / Scope menu:

Horizontal
If you want to measure very slow signals the slowest possible timebase can be increased up to 10 s/div (this shows 100 s on the screen).
Be patient, in AUTO or NORMAL mode the scope will not refresh the trace on screen unless a full block is captured, in ROLL mode the screen is updated permanently.
Longer hold-off time between captured frames allows to lower the CPU load, while faster sampling improves the triggering on rare events.

## Graph

Interpolation mode can be either Off, Linear, Step or Sinc :
- Off displays only the real sampled points, difficult to detect with fast time base.
- Linear connects these points by straight lines, showing an continuous time curve.
- Step connects the points by steps, making it easier to see the real samples values.
- Sinc interpolates with a bandlimited rounded curve if too few values are on screen, else linear. It uses the simple heuristic: 'displayed values' < 'screen width in pixels'.

## Digital phosphor depth defines the numbers of fading previous traces on the screen.

## Export zoomed screen in double height is applied to exported hardcopy images as shown on the next page.

## Measurement cursors position can be either left or right of the scope's screen.

## The program Configuration can be chosen in Oscilloscope / Settings / Scope menu:

## The scope settings are automatically saved between sessions - for each unit individually based on the serial number. Automatic saving on exit can be deactivated, e.g. to always start with a predefined setup.

## It is also possible to discard all user settings and restart the next time with default settings.

## If you have modified the HW of the scope to support AC coupling (see detailed info in the Help menu), tick the box here to use this function after the next restart.

### Data Export

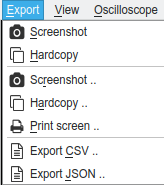
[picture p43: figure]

The Export CSV function allows to store the measured samples and the resulting spectral values as a *.csv file (comma separated values).

All 20000 voltage samples as well as all 10001 calculated spectral components of all active channels are stored.

The values are stored as
SI basic units:
seconds, volts, hertz and dB.

The field separator, usually a comma, is automatically changed to a semicolon for countries where the comma is used as the decimal separator, e.g. Germany.

Export JSON stores the samples in JSON format with the same SI basic units as above.

The Screenshot .. function captures the program window as a *.png picture (*.jpg is also possible) or a *.pdf file.

Screenshot stores as <DATE>_<TIME>.png without asking.

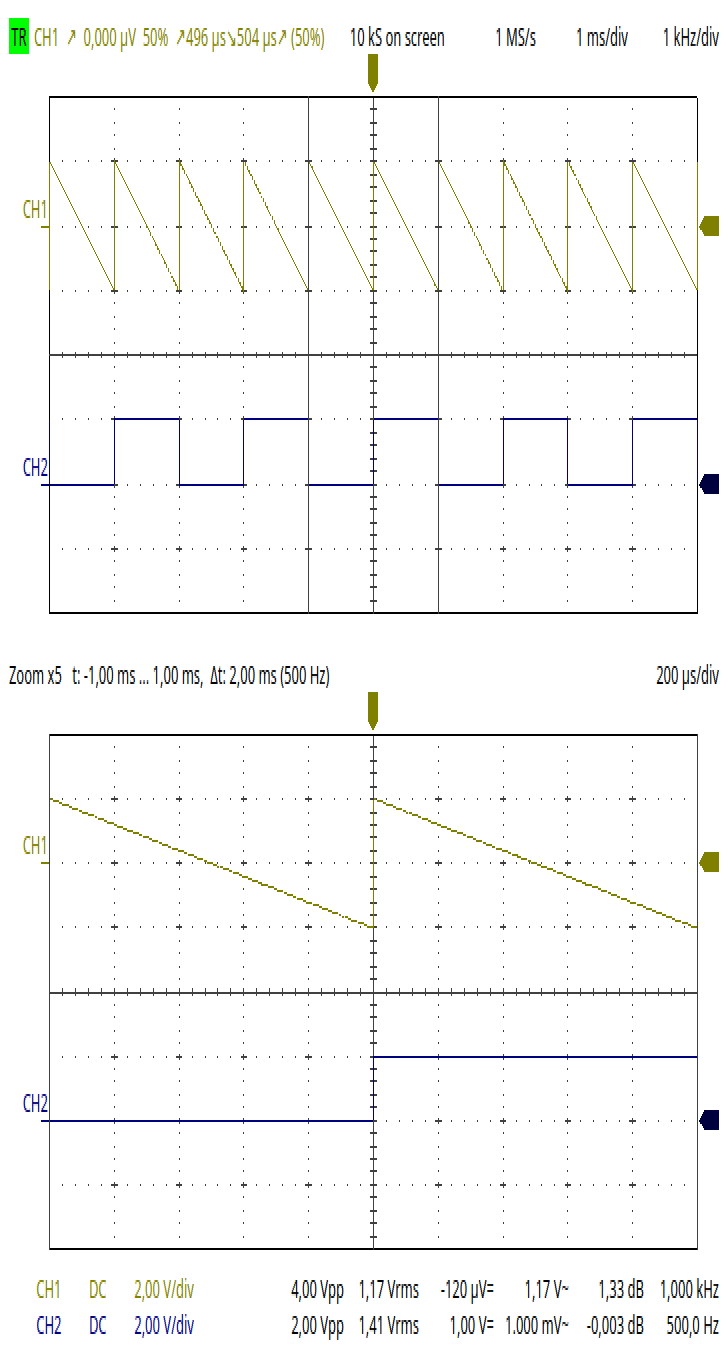
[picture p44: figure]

The Hardcopy .. function creates an image/pdf of the scope screen in printer colors that are optimized for print on paper; Hardcopy stores as <DATE>_<TIME>.png without asking.

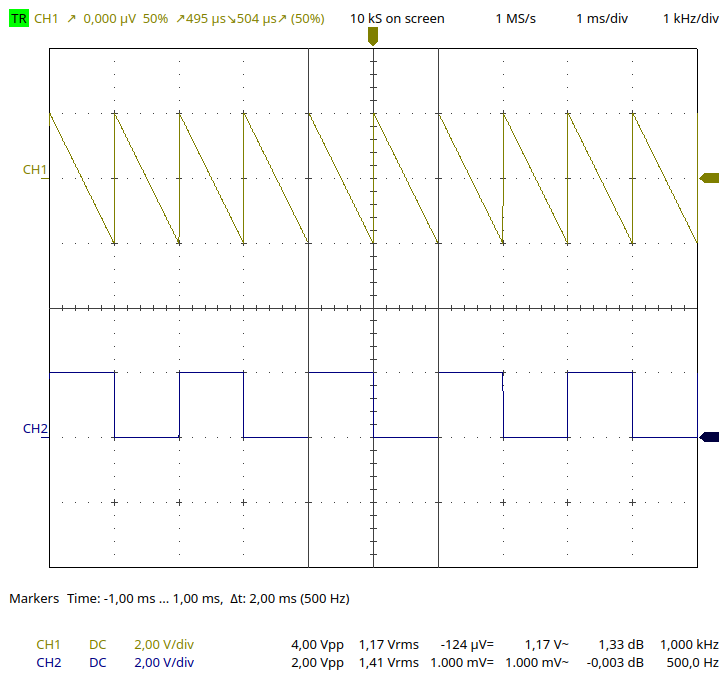
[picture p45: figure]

A zoomed screen is scaled to double height, configuration: Oscilloscope/Settings/Scope

The Print .. function sends the hardcopy screen content to the printer in pdf format.

# Appearance

OpenHantek6022 provides translations for Chinese, French, German, Italian, Polish, Portuguese, Russian and Spanish. The Chinese, French, German, Polish, Russian and Spanish translations are complete, the other languages are almost complete. The translations were provided and checked by native speakers. Volunteers for other languages are welcome!

# OpenHantek6022 automatically adapts to the used light or dark system or user theme.

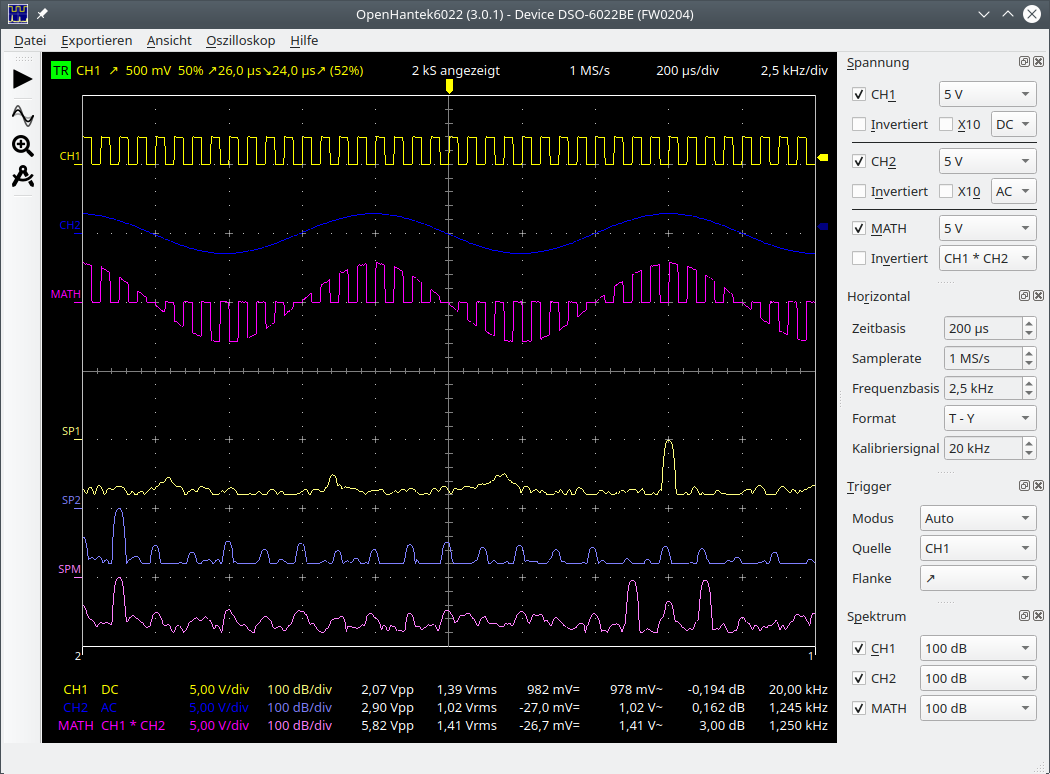
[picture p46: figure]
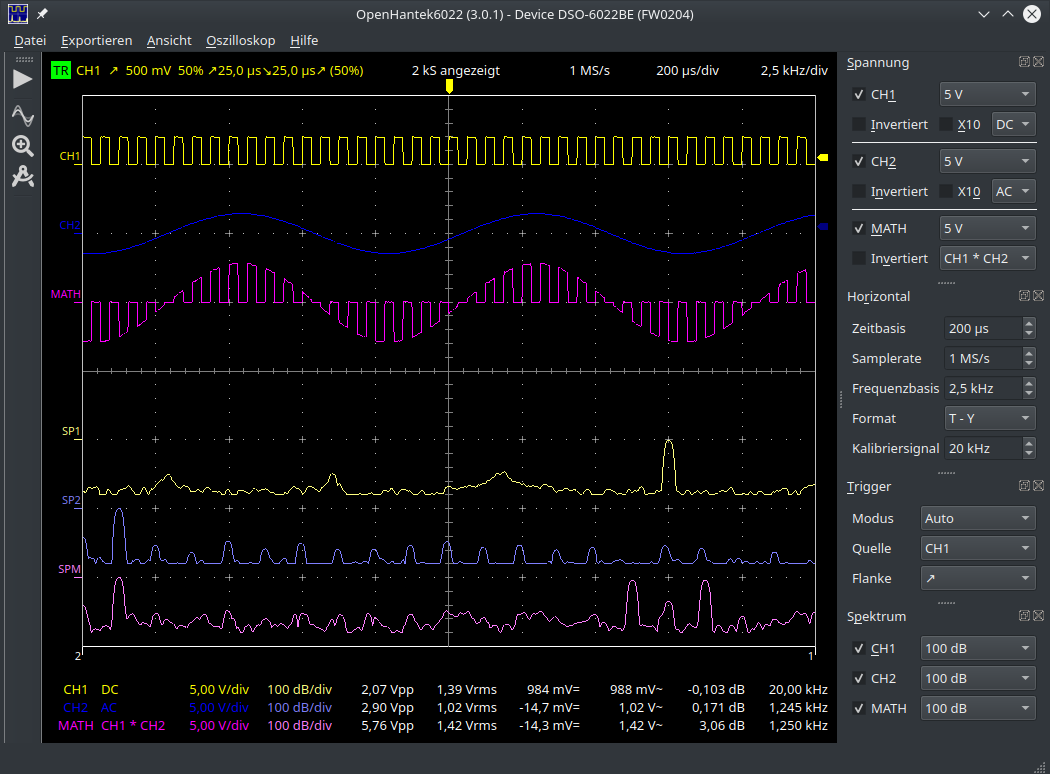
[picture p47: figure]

# The colors of the traces on the screen as well as the exported png / pdf documents can be adjusted individually in the menu Oscilloscope / Settings / Colors.

# You can also select Fusion style instead of the system theme style, active after next restart. Especially on Linux systems Fusion gives a more compact window that fits perfectly on smaller screens, e.g. HD1280x720 of older Laptops.

# It is possible to select an Auto (=System), Light or Dark Theme, active after next restart.

## Font size can be set from 6 to 24 point after next restart (default = 10). This setting allows to scale the text and widgets to adapt for different screen sizes and dpi values.

# Command Line Options

OpenHantek6022 offers these command line options:

Usage: ./OpenHantek [options]

Options:

-h, --help Displays this help.

-v, --version Displays version information.

-d, --demoMode Demo mode without scope HW

-e, --useGLES Use OpenGL ES instead of OpenGL

--useGLSL120 Force OpenGL SL version 1.20

--useGLSL150 Force OpenGL SL version 1.50

-i, --international Show the international interface, do not

translate

-f, --font <Font> Define the system font

-s, --size <Size> Set the font size (default=10, 0: automatic from dpi)

-c, --condensed <Condensed> Set the font condensed value (default = 87)

--resetSettings Reset persistent settings, start with default

--verbose <Level> Verbose tracing of program startup, ui and processing

The –use… options allow to force a different OpenGL version than the automatically detected (e.g. in case of display artifacts).

The font setting options allow to adapt the appearance for very small and very big screens, the widgets will be scaled accordingly. The font size is also available from the settings menu.

The verbose setting allows to trace the program startup/shutdow, the user interaction and the processing with increasing details, output goes to stderr: 0: quiet; 1,2: startup and shutdown; 3,4: +user interaction; 5,6: +data processing (lot of output!).

# Tips and Tricks for the Experienced User

Under Linux the program tries to get a higher real-time priority to yield a slightly better USB allocation, especially at high sampling rates (30 MS/s for one channel, 15MS/s for two channels). To make this possible, the user must be a member of a real-time group. This could be e.g. the group audio, if you are performing professional audio processing with JACK.

1. set limits in /etc/security/limits.d:

@audio - rtprio 90

2. add user to the group, e.g. audio:

usermod -a -G audio <your_user_name>

# But you can also set the limits for your user only:

1. set limits in /etc/security/limits.d:

<your_user_name> - rtprio 90

These settings work best when you're using a realtime-kernel, e.g. the debian package linux-image-rt-amd64. But also the recent standard kernels allow to set higher priority and better scheduling if enabled for your user.

# Hantek6022 Analog Front End (One Channel)


# The input signal Vin is divided 1:10 by a frequency compensated resistors R27/17 and R31/21. Clamping diode A7 limits Ve to ±5 V (equates Vin = ±50 V). U11/7 together with the analog multiplexer amplifies Ve by 1X, 2X, 5X or 10X (Vout).

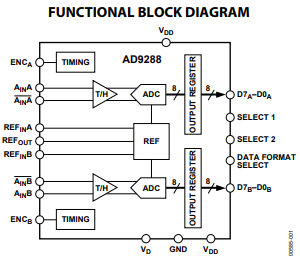
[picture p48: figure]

# Vout is fed into the ADC AD9288 that measures the difference between Ain and /Ain and converts the difference input voltage range -512 mV .. +512 mV into digital values 0x00 .. 0xFF (0 V equates 0x80).

# Unfortunately Hantek decided to operate the ADC far out of spec with a common mode voltage Vc = 0 V, which is contrary to the data sheet requirement for the common mode voltage:

# Vc = 0.3 x Vd – 0.2 V .. 0.3 x Vd + 0.2 V, with Vd = 3 V → Vc = 2.7 V .. 3.1 V

# Probably due to this misdesign the first 1000..1500 samples of a measured block are unstable, OpenHantek6022 bypasses this behavior by sampling more values and dropping the first ~2000.

# Another bad design decision by Hantek was that the oscilloscope does not support AC coupling of input signals – but you can modify the hardware yourself. A short AC modification howto is available via the Help menu or from github:

https://github.com/OpenHantek/OpenHantek6022/blob/main/docs/HANTEK6022_AC_Modification.pdf

# Hantek6022 Digital Back End

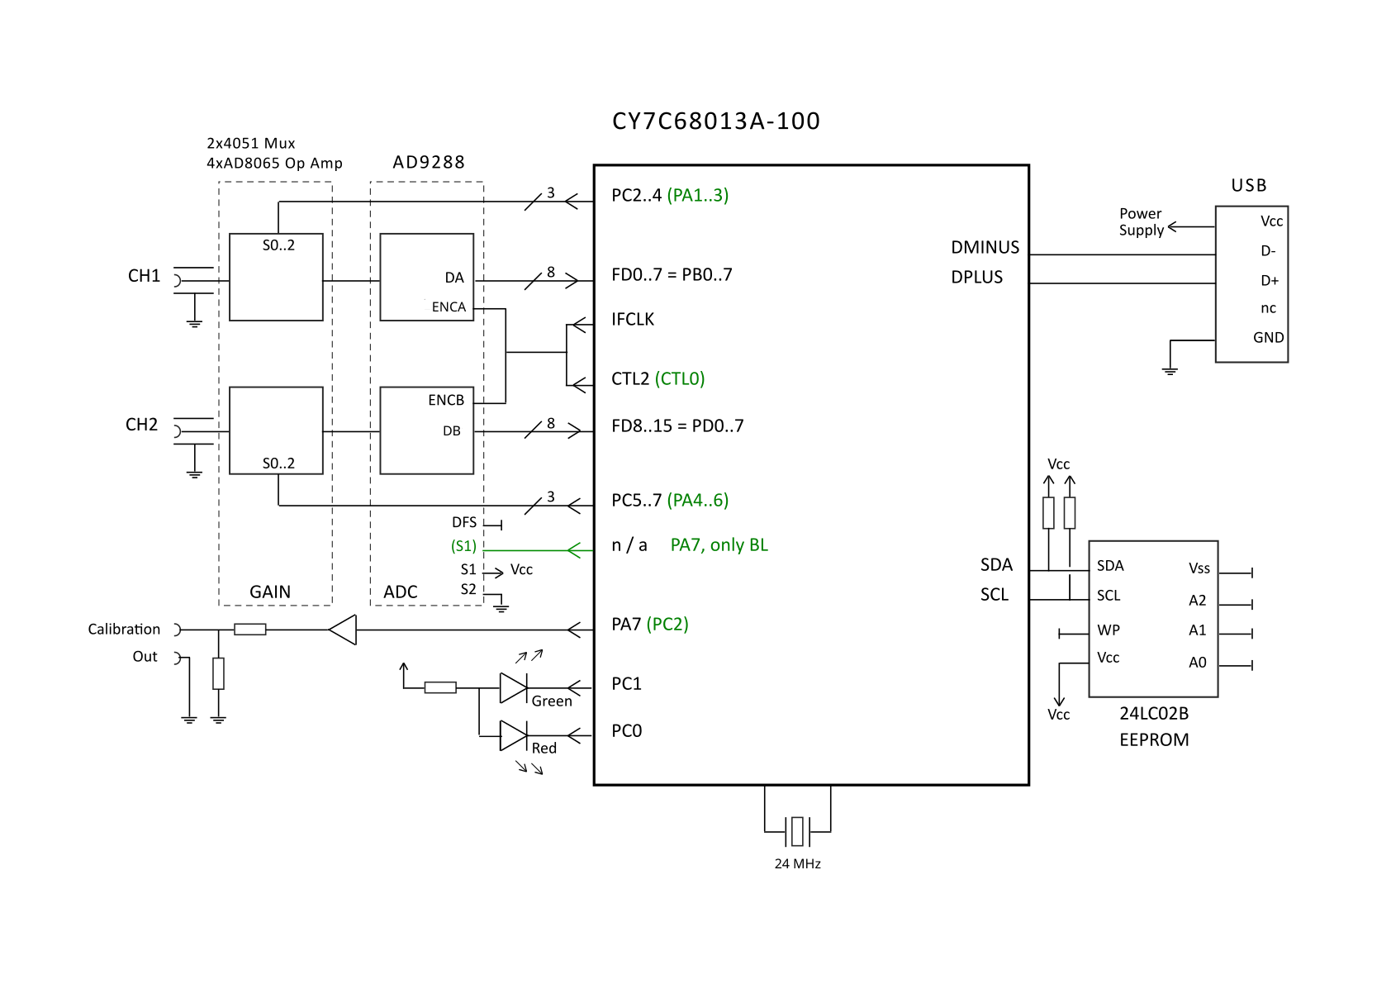
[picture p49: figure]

The Hantek6022 (BE & BL) backend is built around the EzUSB processor CY7C68013A that handles USB communication, ADC timing, front-end channel gain setting and also generates the calibration output signal. Hantek 6022BE and 6022BL (in scope mode) differ slightly in the use of the processor pins (different BL pins in green), but otherwise work identically.

EzUSB does not store the user firmware permanently in flash memory, it must be uploaded to RAM each time the unit is turned on. The program OpenHantek6022 checks if the correct firmware version is loaded. In case it detects no FW or a wrong FW version (e.g. because of using the scope with sigrok or the original Hantek software before) the correct firmware will be uploaded automatically. If no device is detected, disconnect / reconnect the USB plug.

OpenHantek6022 User Manual 17/17 2021-12-13

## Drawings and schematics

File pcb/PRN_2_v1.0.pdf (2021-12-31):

SpiceOrder 2 | SpiceOrder 1 SpiceOrder 1 SpiceOrder 2 SpiceOrder 1 | SpiceOrder 1 SpiceOrder 2 | SpiceOrder 2

## AMS1117-3.3

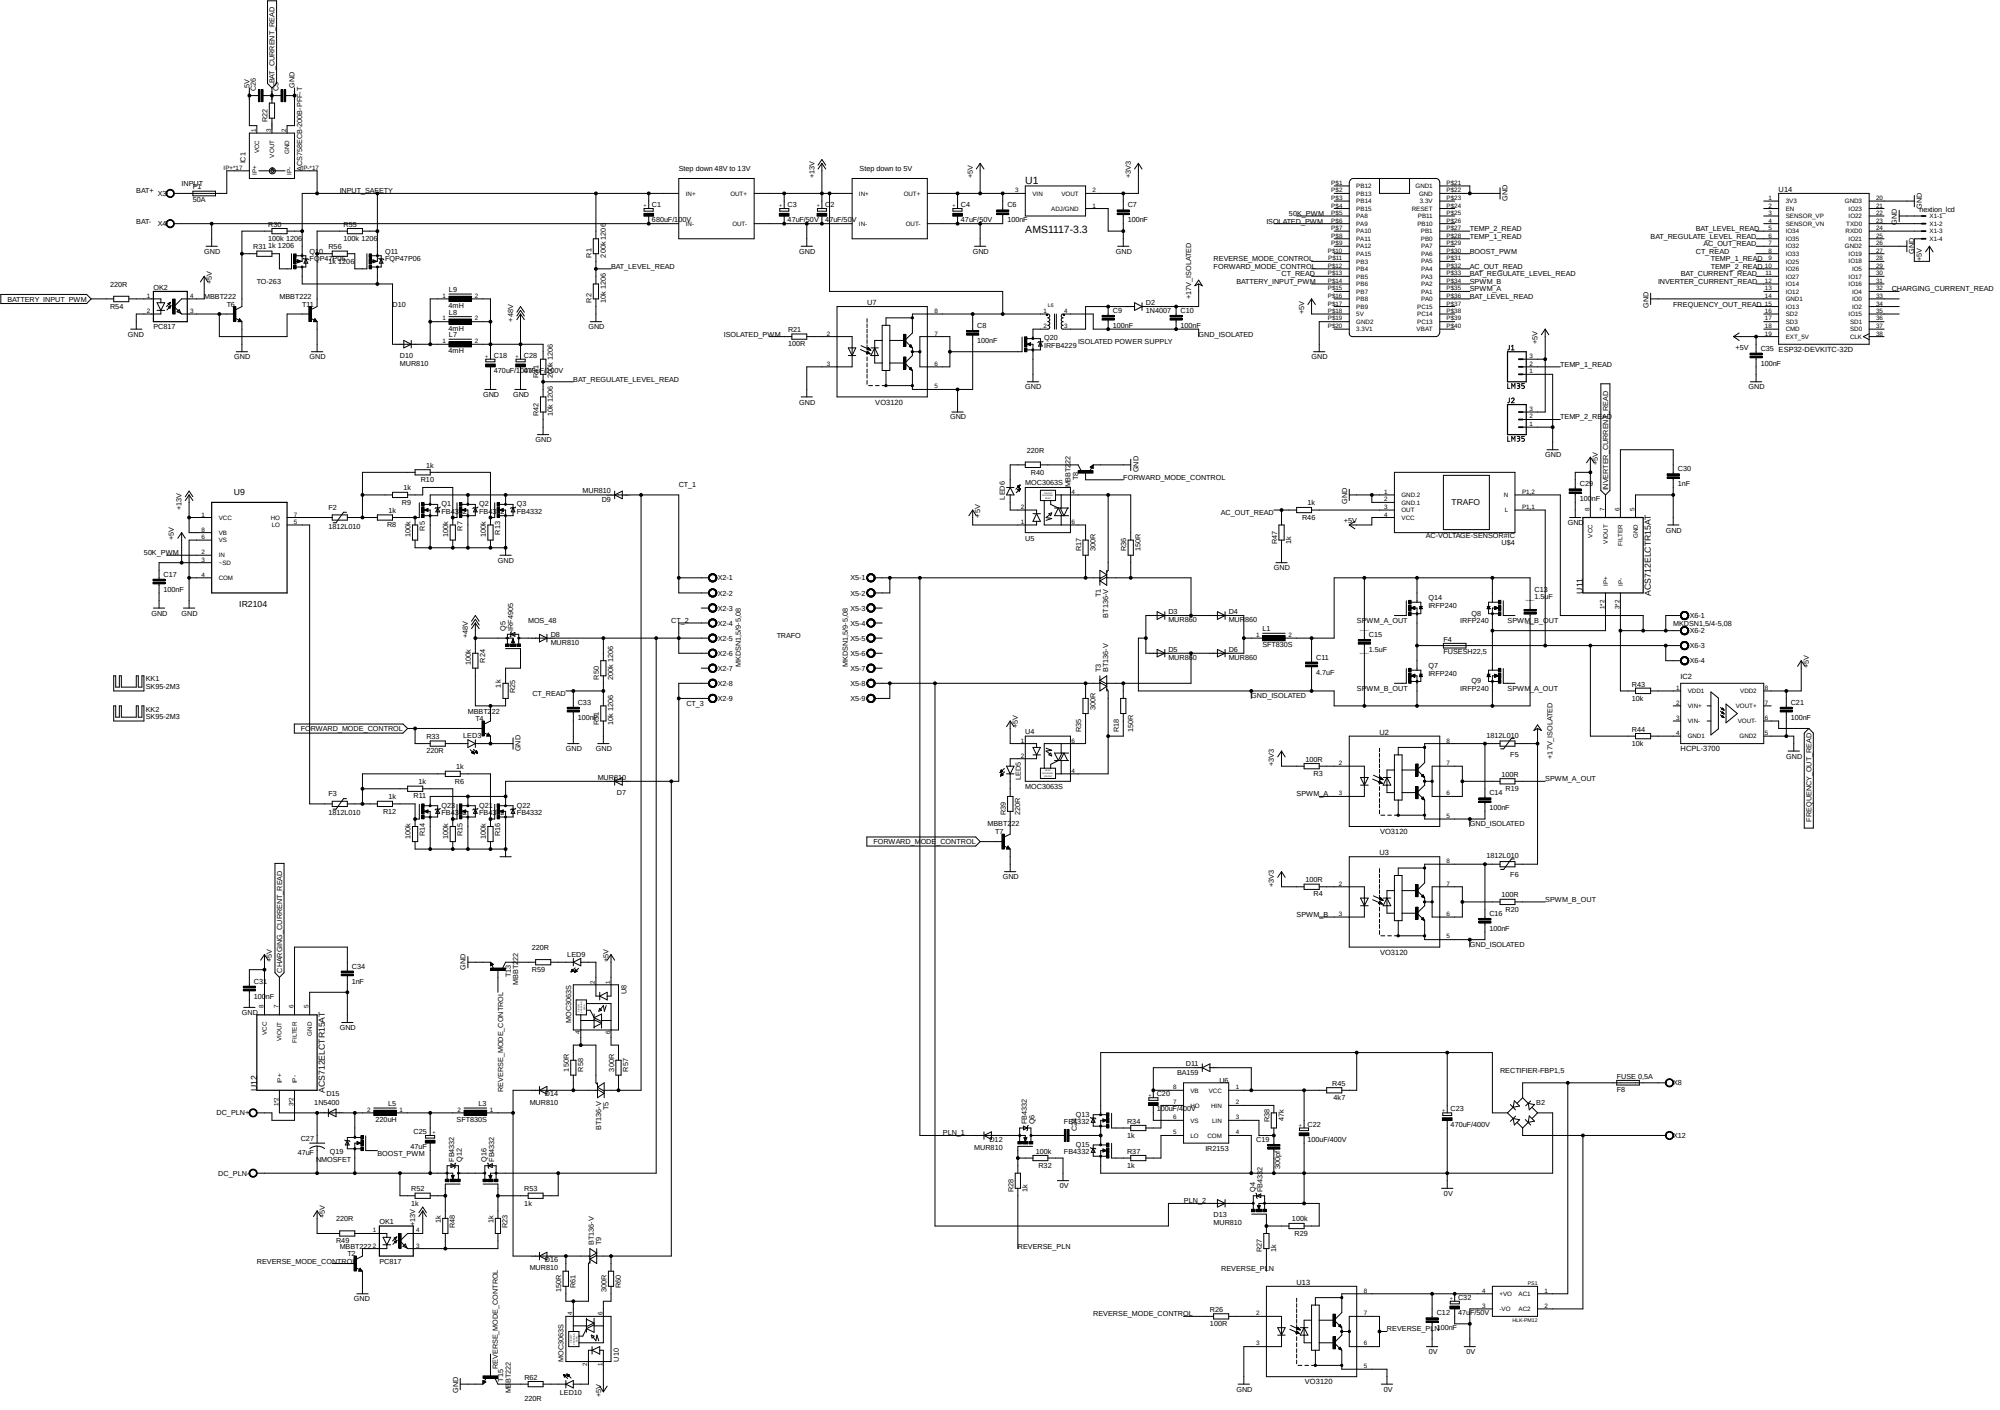
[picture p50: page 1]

AC-VOLTAGE-SENSOR#IC GND

CIRCUIT ZERO CROSSING CIRCUIT ZERO CROSSING CIRCUIT

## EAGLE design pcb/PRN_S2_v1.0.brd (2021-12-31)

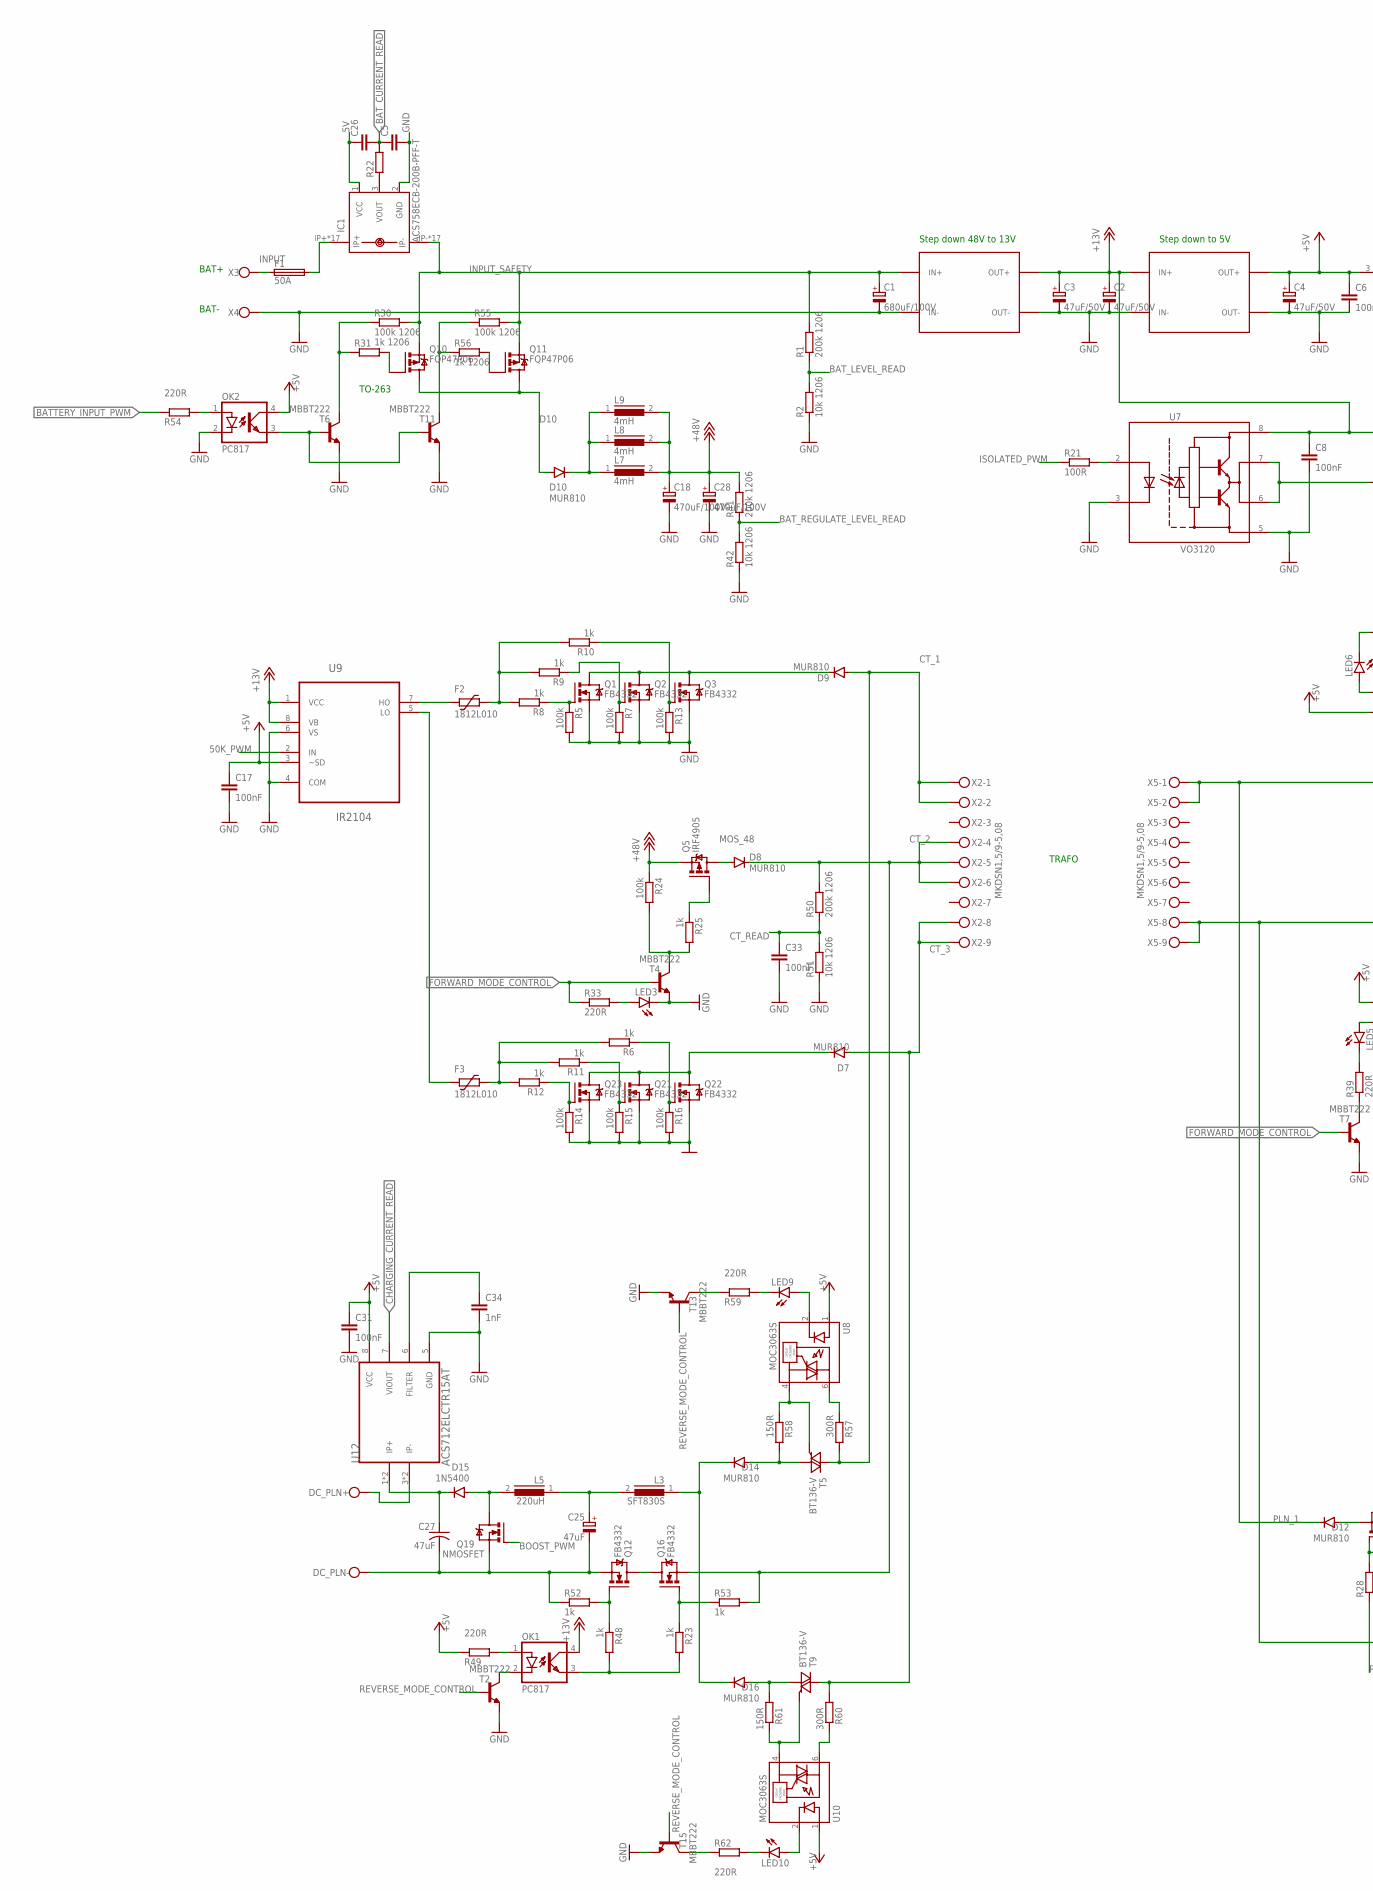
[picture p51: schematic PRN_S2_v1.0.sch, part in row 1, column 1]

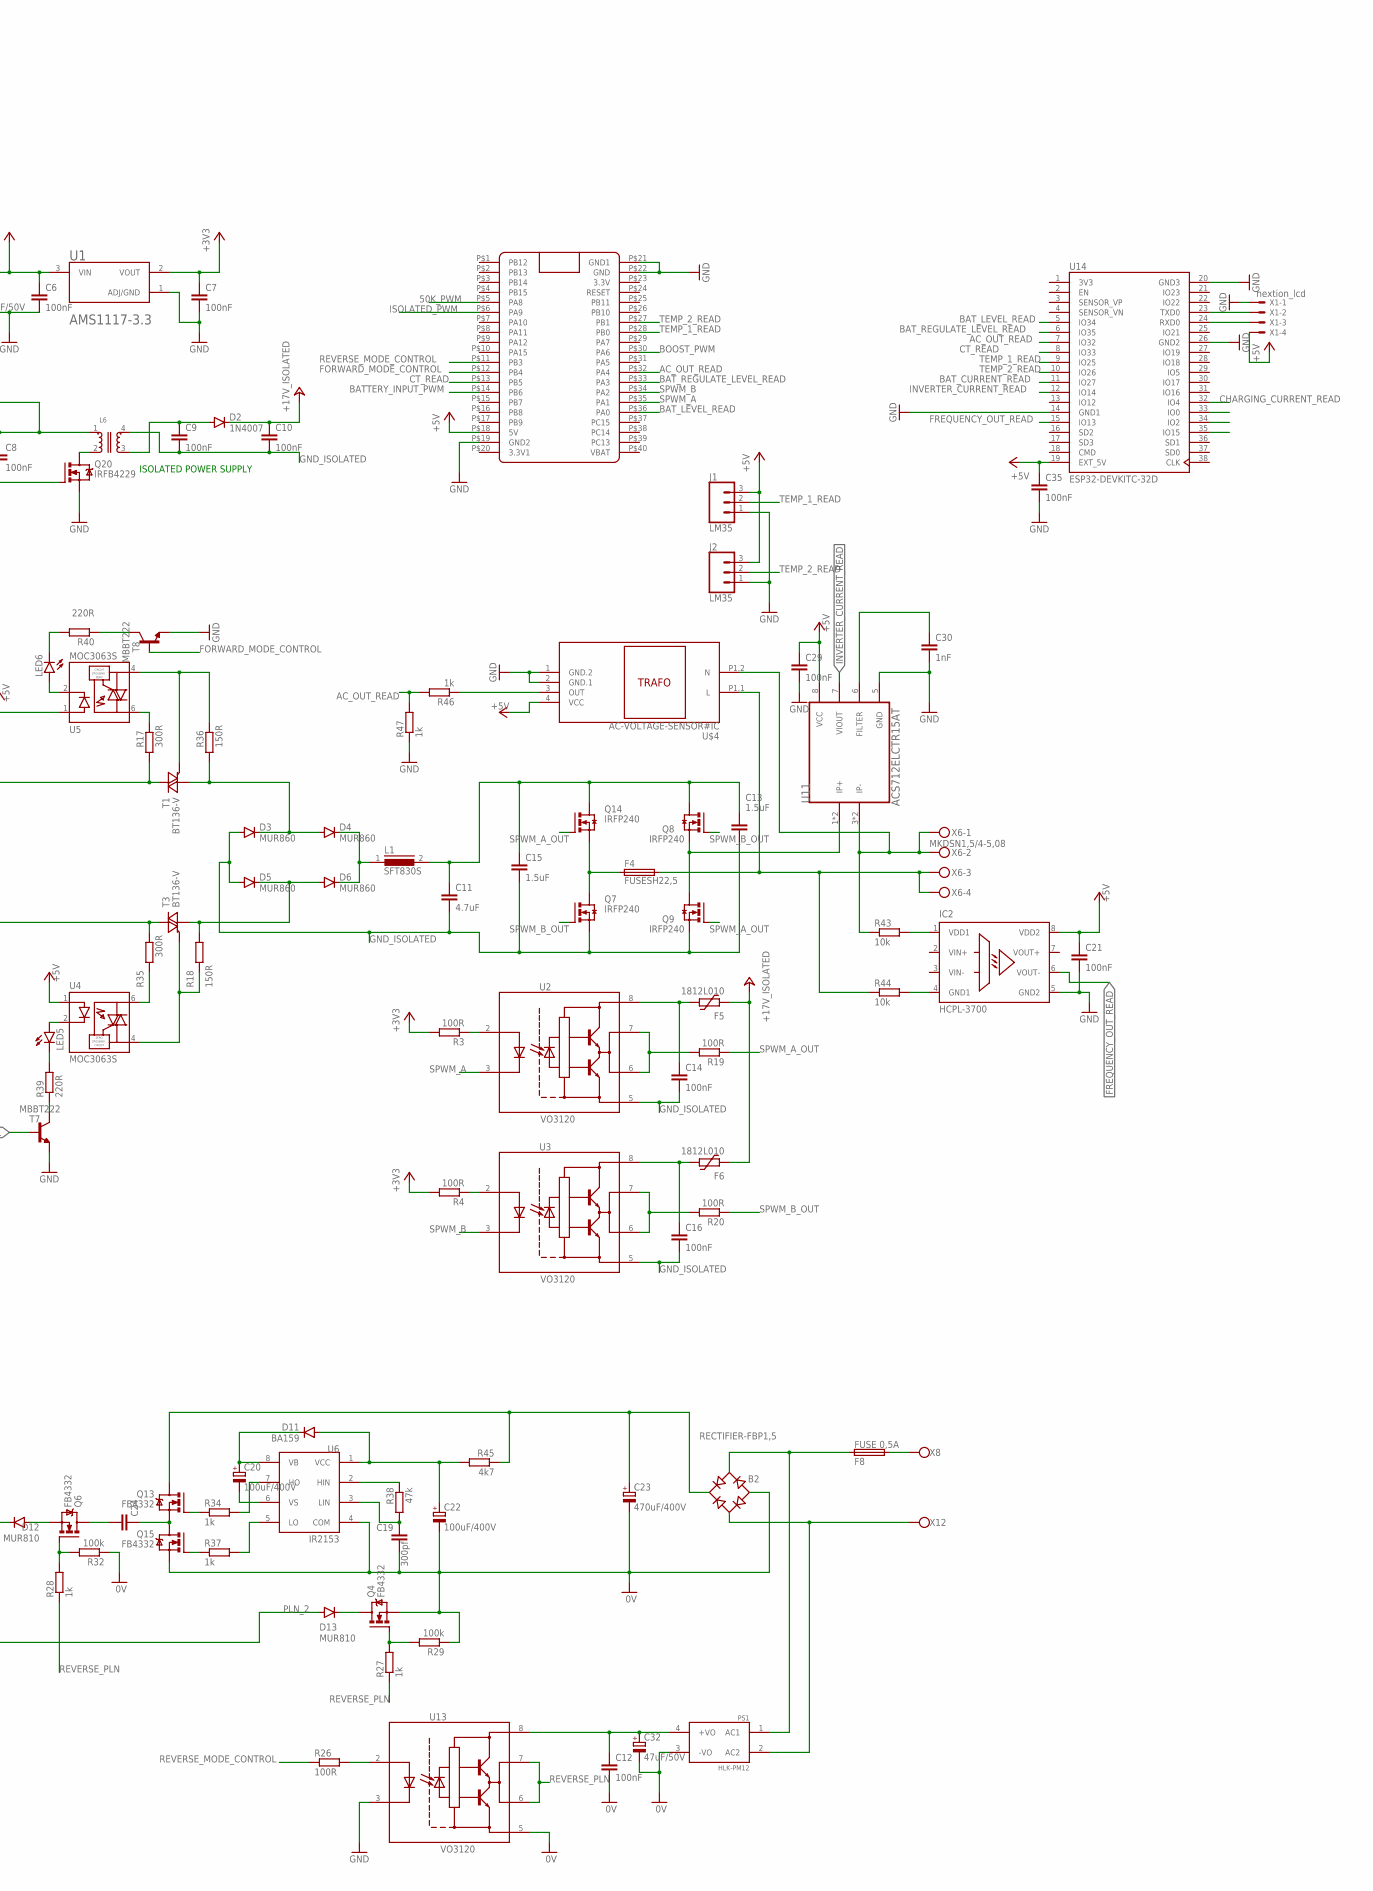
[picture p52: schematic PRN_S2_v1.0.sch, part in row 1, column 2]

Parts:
B2: RECTIFIER-FBP1,5; FBP1,5
C1: 680uF/100V; E7,5-18
C2, C3, C4, C32: 47uF/50V; E2,5-6
C5, C26: CC0603; C0603
C6, C7, C14, C16, C17, C21, C29, C31, C35: 100nF; C0805K
C8, C9, C10, C12, C33: 100nF; C050-025X075
C11: 4.7uF; C275-113X316
C13, C15: 1.5uF; C150-091X182
C18, C28: 470uF/100V; E7,5-18
C19: 300pf; C0805
C20, C22: 100uF/400V; E7,5-18
C23: 470uF/400V; EB35D
C24: C-EU325-137X374; C325-137X374
C25: 47uF; E7,5-18
C27: 47uF; C050-050X075
C30, C34: 1nF; C0805K
D2: 1N4007; DO41-10
D3, D4, D5, D6: MUR860; TO220ACS
D7, D8, D9, D10, D12, D13, D14, D16: MUR810; TO220ACS
D11: BA159; DO41-10
D15: 1N5400; DO201-15
DC_PLN+: W237-112
DC_PLN-: W237-112
F1: 50A; GSH15
F2, F3, F5, F6: 1812L010; 1812L
F4: FUSESH22,5; SH22,5
F8: FUSE 0,5A; SH22,5
IC1: ACS758ECB-200B-PFF-T; CB-PFF
IC2: HCPL-3700; DIL08
J1, J2: LM35; 1X03
L1, L3: SFT830S
L5: 220uH; SFT830S
L6: WE-AMT_750082107
L7, L8, L9: 4mH; SFT830S
LED3, LED5, LED6, LED9, LED10: LEDCHIPLED_0805; CHIPLED_0805
OK1, OK2: PC817; DIL04
PS1: HLK-PM12; CONV_HLK-PM03
Q1, Q2, Q3, Q4, Q6, Q12, Q13, Q15, Q16, Q21, Q22, Q23: FB4332; TO220BV
Q5: IRF4905; TO220BV
Q7, Q8, Q9, Q14: IRFP240; TO247BV
Q10, Q11: FQP47P06; TO220BV
Q19: NMOSFET; TO220BV
Q20: IRFB4229; TO220BV
R1, R41, R50: 200k 1206; R1206
R2, R42, R51: 10k 1206; R1206
R3, R4, R19, R20, R21, R26: 100R; R0805
R5, R7, R13, R14, R15, R16, R24, R29, R32: 100k; R0805
R6, R8, R9, R10, R11, R12, R23, R25, R27, R28, R48, R52, R53: 1k; R0805
R17, R35, R57, R60: 300R; 0207/15
R18, R36, R58, R61: 150R; 0207/15
R22: RR0603; R0603
R30, R55: 100k 1206; R1206
R31, R56: 1k 1206; R1206
R33, R39, R40, R49, R54, R59, R62: 220R; R0805
R34, R37: 1k; 0207/12
R38: 47k; 0617/17
R43, R44: 10k; 0207/12
R45: 4k7; 0617/17
R46, R47: 1k; R1206
T1, T3, T5, T9: BT136-V; TO220BV
T2, T4, T6, T7, T8, T11, T13, T15: MBBT222; SOT23-EBC
U1: AMS1117-3.3; SOT229P700X180-4N
U2, U3, U7, U13: VO3120; DIP762W50P254L977H451Q8
U4, U5, U8, U10: MOC3063S; DIP762W50P254L730H500Q6
U6: IR2153; DIL08
U9: IR2104; DIP254P762X533-8
U11, U12: ACS712ELCTR15AT; SOIC127P600X175-8N
U14: ESP32-DEVKITC-32D; MODULE_ESP32-DEVKITC-32D
U$1, U$2: DC-DC-STEP-DOWN-LM2596
U$3: BLUE_PILL
U$4: AC-VOLTAGE-SENSOR#IC
X1: nextion_lcd; 22-23-2041
X2, X5: MKDSN1,5/9-5,08
X3, X4, X8, X12: W237-112
X6: MKDSN1,5/4-5,08

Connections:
0V: B2.-, C12.2, C19.2, C22.-, C23.-, C32.-, PS1.3 (-VO), Q4.S, Q15.S, R29.1, R32.1, U6.4 (COM), U13.5 (VEE)
3V3: U14.1 (3V3)
5V: C26.1, IC1.1 (VCC)
50K_PWM: U9.2 (IN), U$3.P$5 (PA8)
+3V3: C7.1, R3.2, R4.2, U1.2 (VOUT)
+5V: C4.+, C6.1, C17.1, C21.1, C29.1, C31.1, C35.1, IC2.8 (VDD2), J1.3, J2.3, OK2.4 (COL), R49.1, U1.3 (VIN), U4.1 (ANODE), U5.1 (ANODE), U8.1 (ANODE), U9.3 (~SD), U10.1 (ANODE), U11.8 (VCC), U12.8 (VCC), U14.19 (EXT_5V), U$2.OUT+, U$3.P$18 (5V), U$4.4 (VCC), X1.4
+12V: C2.+, C3.+, C8.1, L6.1, OK1.4 (COL), U7.8 (VCC), U9.1 (VCC), U9.8 (VB), U$1.OUT+, U$2.IN+
+18V: C18.+, C28.+, L7.2, L8.2, L9.2, Q5.S, R24.1, R41.2
+24V: C10.1, D2.C, F5.2, F6.2
A: D9.C, Q1.D, Q2.D, Q3.D
AC_OUT_READ: R46.2, R47.2, U14.7 (IO32), U$3.P$32 (PA4)
AFTER_D10: D10.C, L7.1, L8.1, L9.1
B: D7.C, Q21.D, Q22.D, Q23.D
BATTERY_INPUT_PWM: R54.1, U$3.P$14 (PB6)
BAT_CURRENT_READ: C5.1, C26.2, R22.2, U14.11 (IO27)
BAT_LEVEL_READ: R1.1, R2.2, U14.5 (IO34), U$3.P$36 (PA0)
BAT_REGULATE_LEVEL_READ: R41.1, R42.2, U14.6 (IO35), U$3.P$33 (PA3)
BOOST_PWM: Q19.G, U$3.P$30 (PA6)
CHARGING_CURRENT_READ: U12.7 (VIOUT), U14.32 (IO4)
CT_1: D9.A, R57.1, T5.T2 (A2), X2.1, X2.2
CT_2: D8.C, Q16.S, R50.2, R53.2, X2.4, X2.5, X2.6
CT_3: D7.A, R60.1, T9.T2 (A2), X2.8, X2.9
CT_READ: C33.1, R50.1, R51.2, U14.8 (IO33), U$3.P$13 (PB5)
D10: D10.A, Q10.D, Q11.D
DC_PLN: C27.1, D15.C, U12.1 (IP+), U12.2 (IP+)
DC_PLN+: DC_PLN+.1, U12.3 (IP-), U12.4 (IP-)
DC_PLN-: C25.-, C27.2, DC_PLN-.1, Q12.S, Q19.S, R52.1
FORWARD_MODE_CONTROL: R33.1, T4.B, T7.B, T8.B, U$3.P$12 (PB4)
FREQUENCY_OUT_READ: IC2.6 (VOUT-), U14.15 (IO13)
GG: OK2.3 (EMIT), T6.B, T11.B
GND: C1.-, C2.-, C3.-, C4.-, C5.2, C6.2, C7.2, C8.2, C17.2, C18.-, C21.2, C28.-, C29.2, C30.2, C31.2, C33.2, C34.2, C35.2, IC1.2 (GND), IC2.5 (GND2), J1.1, J2.1, LED3.C, OK2.2 (C), Q1.S, Q2.S, Q3.S, Q20.S, Q21.S, Q22.S, Q23.S, R2.1, R5.2, R7.2, R13.2, R14.2, R15.2, R16.2, R42.1, R47.1, R51.1, T2.E, T4.E, T6.E, T7.E, T8.E, T11.E, T13.E, T15.E, U1.1 (ADJ/GND), U7.3 (C), U7.5 (VEE), U9.4 (COM), U9.6 (VS), U11.5 (GND), U12.5 (GND), U13.3 (C), U14.14 (GND1), U14.20 (GND3), U14.26 (GND2), U$1.IN-, U$1.OUT-, U$2.IN-, U$2.OUT-, U$3.P$19 (GND2), U$3.P$21 (GND1), U$3.P$22 (GND), U$4.1 (GND.2), U$4.2 (GND.1), X1.1, X4.1
GND_ISOLATED: C9.2, C10.2, C11.2, C13.2, C14.2, C15.2, C16.2, D3.A, D5.A, L6.4 (2), Q7.S, Q9.S, U2.5 (VEE), U3.5 (VEE)
INPUT: F1.1, X3.1
INPUT_SAFETY: C1.+, IC1.IP-, IC1.IP-@2 (IP-), IC1.IP-@3 (IP-), IC1.IP-@4 (IP-), IC1.IP-@5 (IP-), IC1.IP-@6 (IP-), IC1.IP-@7 (IP-), IC1.IP-@8 (IP-), IC1.IP-@9 (IP-), IC1.IP-@10 (IP-), IC1.IP-@11 (IP-), IC1.IP-@12 (IP-), IC1.IP-@13 (IP-), IC1.IP-@14 (IP-), IC1.IP-@15 (IP-), IC1.IP-@16 (IP-), IC1.IP-@17 (IP-), Q10.S, Q11.S, R1.2, R30.2, R55.2, U$1.IN+
INVERTER_CURRENT_READ: U11.7 (VIOUT), U14.12 (IO14)
IN_48V: F1.2, IC1.IP+, IC1.IP+@2 (IP+), IC1.IP+@3 (IP+), IC1.IP+@4 (IP+), IC1.IP+@5 (IP+), IC1.IP+@6 (IP+), IC1.IP+@7 (IP+), IC1.IP+@8 (IP+), IC1.IP+@9 (IP+), IC1.IP+@10 (IP+), IC1.IP+@11 (IP+), IC1.IP+@12 (IP+), IC1.IP+@13 (IP+), IC1.IP+@14 (IP+), IC1.IP+@15 (IP+), IC1.IP+@16 (IP+), IC1.IP+@17 (IP+)
ISOLATED_PWM: R21.1, U$3.P$6 (PA9)
MOS_48: D8.A, Q5.D
unnamed: Q5.G, R25.1
unnamed: Q20.G, U7.6 (VO1), U7.7 (VO2)
unnamed: L6.2 (4), Q20.D
unnamed: Q10.G, R31.2
unnamed: Q11.G, R56.2
unnamed: IC1.3 (VOUT), R22.1
unnamed: F2.1, R8.2, R9.2, R10.2
unnamed: C9.1, D2.A, L6.3
unnamed: Q13.G, R34.1
unnamed: LED3.A, R33.2
unnamed: F3.1, R6.2, R11.2, R12.2
unnamed: Q2.G, R7.1, R9.1
unnamed: Q21.G, R11.1, R15.1
unnamed: Q22.G, R6.1, R16.1
unnamed: R46.1, U$4.3 (OUT)
unnamed: C30.1, U11.6 (FILTER)
unnamed: U14.23 (TXD0), X1.2
unnamed: R17.2, U5.6 (MAIN_TERM1)
unnamed: R18.1, T3.G, U4.4 (MAIN_TERM2)
unnamed: D13.C, Q4.D
unnamed: R36.2, T1.G, U5.4 (MAIN_TERM2)
unnamed: D3.C, D4.A, R36.1, T1.T1 (A1)
unnamed: C14.1, F5.1, U2.8 (VCC)
unnamed: D4.C, D6.C, L1.1
unnamed: D5.C, D6.A, R18.2, T3.T1 (A1)
unnamed: R19.2, U2.6 (VO1), U2.7 (VO2)
unnamed: C34.1, U12.6 (FILTER)
unnamed: F4.1, Q7.D, Q14.S
unnamed: C11.1, C13.1, C15.1, L1.2, Q8.D, Q14.D
unnamed: R43.1, U11.3 (IP-), U11.4 (IP-), U$4.P1.2 (N), X6.1, X6.2
unnamed: F4.2, R44.1, U$4.P1.1 (L), X6.3, X6.4
unnamed: Q8.S, Q9.D, U11.1 (IP+), U11.2 (IP+)
unnamed: LED5.A, U4.2 (CATHODE)
unnamed: R20.2, U3.6 (VO1), U3.7 (VO2)
unnamed: C16.1, F6.1, U3.8 (VCC)
unnamed: Q15.G, R37.1
unnamed: R3.1, U2.2 (A)
unnamed: R4.1, U3.2 (A)
unnamed: R21.2, U7.2 (A)
unnamed: R24.2, R25.2, T4.C
unnamed: F3.2, U9.5 (LO)
unnamed: C24.1, Q13.S, Q15.D
unnamed: Q12.G, R48.1, R52.2
unnamed: C24.2, Q6.D
unnamed: Q6.G, R28.2, R32.2
unnamed: R35.1, U4.6 (MAIN_TERM1)
unnamed: R26.2, U13.2 (A)
unnamed: OK1.2 (C), T2.C
unnamed: IC2.4 (GND1), R44.2
unnamed: F2.2, U9.7 (HO)
unnamed: Q1.G, R5.1, R8.1
unnamed: R55.1, R56.1, T11.C
unnamed: Q23.G, R12.1, R14.1
unnamed: Q4.G, R27.2, R29.2
unnamed: R30.1, R31.1, T6.C
unnamed: U14.24 (RXD0), X1.3
unnamed: LED5.C, R39.2
unnamed: Q3.G, R10.1, R13.1
unnamed: R39.1, T7.C
unnamed: LED6.A, U5.2 (CATHODE)
unnamed: LED6.C, R40.2
unnamed: R40.1, T8.C
unnamed: F8.2, X8.1
unnamed: IC2.1 (VDD1), R43.2
unnamed: C12.1, C32.+, PS1.4 (+VO), U13.8 (VCC)
unnamed: R38.1, U6.2 (HIN)
unnamed: C19.1, R38.2, U6.3 (LIN)
unnamed: C20.-, U6.6 (VS)
unnamed: D12.A, Q6.S
unnamed: Q12.D, Q16.D
unnamed: R34.2, U6.7 (HO)
unnamed: R37.2, U6.5 (LO)
unnamed: OK1.3 (EMIT), R23.2, R48.2
unnamed: B2.AC2, PS1.2 (AC2), X12.1
unnamed: B2.AC1, F8.1, PS1.1 (AC1)
unnamed: OK1.1 (A), R49.2
unnamed: B2.+, C23.+, Q13.D, R45.1
unnamed: Q16.G, R23.1, R53.1
unnamed: OK2.1 (A), R54.2
unnamed: R57.2, U8.6 (MAIN_TERM1)
unnamed: R58.2, T5.G, U8.4 (MAIN_TERM2)
unnamed: D15.A, L5.2, Q19.D
unnamed: D14.A, R58.1, T5.T1 (A1)
unnamed: D16.A, R61.1, T9.T1 (A1)
unnamed: D14.C, D16.C, L3.1
unnamed: C25.+, L3.2, L5.1
unnamed: LED9.A, U8.2 (CATHODE)
unnamed: LED9.C, R59.2
unnamed: R59.1, T13.C
unnamed: R60.2, U10.6 (MAIN_TERM1)
unnamed: R61.2, T9.G, U10.4 (MAIN_TERM2)
unnamed: LED10.A, U10.2 (CATHODE)
unnamed: LED10.C, R62.2
unnamed: R62.1, T15.C
PLN_1: D12.C, R17.1, T1.T2 (A2), X5.1, X5.2
PLN_2: D13.A, R35.2, T3.T2 (A2), X5.8, X5.9
REVERSE_MODE_CONTROL: R26.1, T2.B, T13.B, T15.B, U$3.P$11 (PB3)
REVERSE_PLN: R27.1, R28.1, U13.6 (VO1), U13.7 (VO2)
SPWM_A: U2.3 (C), U$3.P$35 (PA1)
SPWM_A_OUT: Q9.G, Q14.G, R19.1
SPWM_B: U3.3 (C), U$3.P$34 (PA2)
SPWM_B_OUT: Q7.G, Q8.G, R20.1
TEMP_1_READ: J1.2, U14.9 (IO25), U$3.P$28 (PB0)
TEMP_2_READ: J2.2, U14.10 (IO26), U$3.P$27 (PB1)
VB: C20.+, D11.C, U6.8 (VB)
VCC: C22.+, D11.A, R45.2, U6.1 (VCC)
VIN+: IC2.2 (VIN+)
VIN-: IC2.3 (VIN-)
VOUT+: IC2.7 (VOUT+)

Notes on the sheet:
BAT+
BAT-
Step down 48V to 13V
Step down to 5V
ISOLATED POWER SUPPLY
TRAFO
TO-263

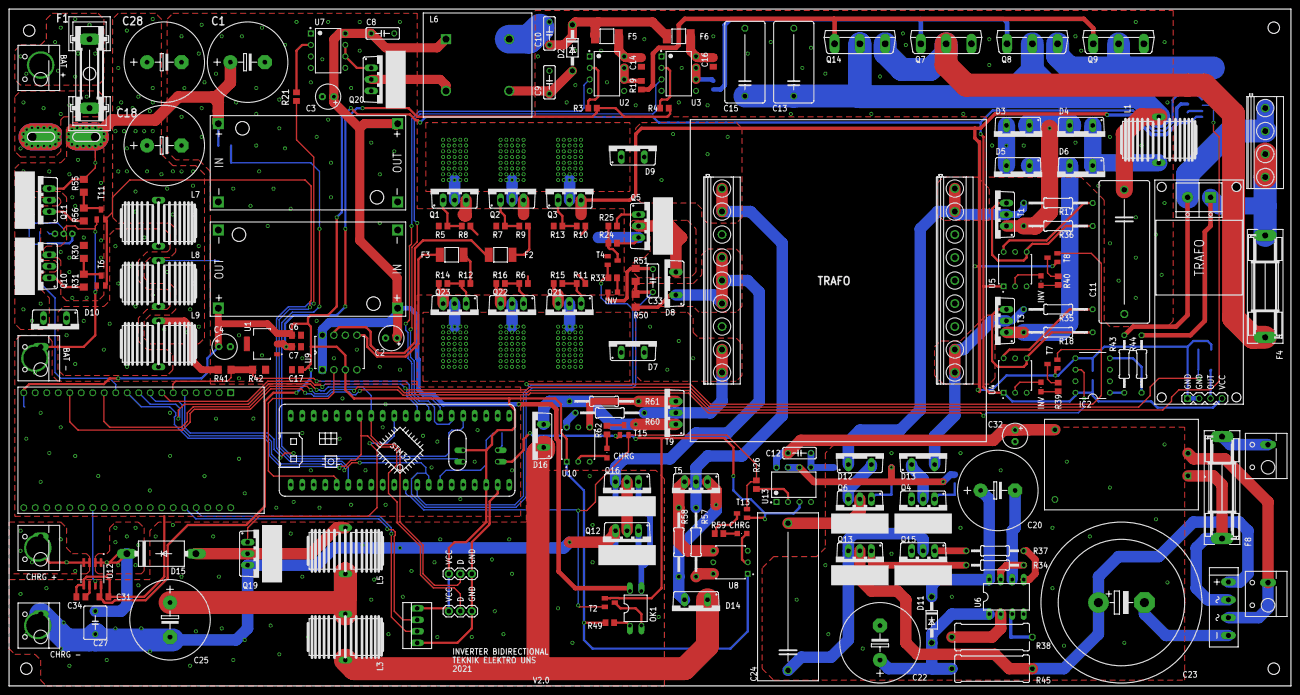
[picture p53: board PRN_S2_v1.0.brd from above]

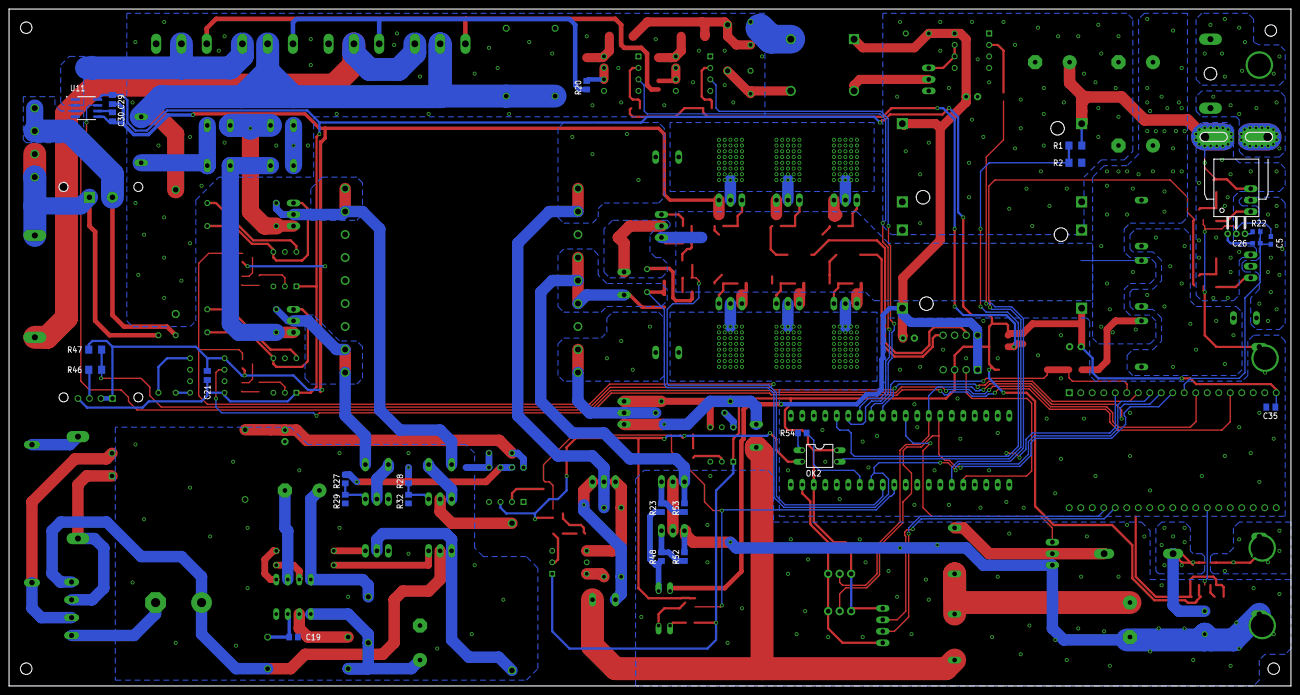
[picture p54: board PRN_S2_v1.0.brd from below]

Board: 2 copper layers, 283.2 x 149.5 mm, 200 parts (25 on the bottom side), 143 nets.

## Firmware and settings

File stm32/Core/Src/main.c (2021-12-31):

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
/* Includes ------------------------------------------------------------------*/
#include "main.h"

/* USER CODE BEGIN Includes */

#include "math.h"

// if math.h didn't works, use the define below
//#define M_PI 3.14159265358979323846264338328

#define F_CPU 72000000		// 72MHz
#define AC_FREQ 50          // 50Hz ac outlet
#define period 600			// Timer 2 period
#define presc 8				// Timer 2 prescale

const int sinDivision = F_CPU/presc/AC_FREQ/period;

uint32_t lookUp[151];
float temp;

// Mode
// Mode 0 for charging
// Mode 1 for inverter
int inverterMode = 0;

// Isolated Buck Converter Properties
int maxIsolatedBuckValue = 144;
int nowIsolatedBuckValue = 0;

// Boost Converter Properties
int maxBoostValue = 288;
int nowBoostValue = 0;

// Input Voltage Properties
int maxInputGateValue = 2000;
int nowInputGateValue = 0;

// Switching Transformer (50KHz)
int maxTrafoSwitchingValue = 144;
int nowTrafoSwitchingValue = 0;

// Analog Reading
uint32_t adcReading[6];

int adcValue0 = 0;
int adcValue1 = 0;
int adcValue2 = 0;
int adcValue3 = 0;
int adcValue4 = 0;
int adcValue5 = 0;

// Voltage Reading
float batteryVoltage;
float inputVoltage;
float ctVoltage;

// Current Reading
float acOutputCurrent;

// Temperature Reading
float temperature1;
float temperature2;


int ledCounter = 0;
/* USER CODE END Includes */

ADC_HandleTypeDef hadc1;
DMA_HandleTypeDef hdma_adc1;

TIM_HandleTypeDef htim1;
TIM_HandleTypeDef htim2;
TIM_HandleTypeDef htim3;
TIM_HandleTypeDef htim4;

void SystemClock_Config(void);
static void MX_GPIO_Init(void);
static void MX_TIM2_Init(void);
static void MX_TIM3_Init(void);
static void MX_DMA_Init(void);
static void MX_ADC1_Init(void);
static void MX_TIM4_Init(void);
static void MX_TIM1_Init(void);
/**
  * @brief  The application entry point.
  * @retval int
  */
int main(void)
{
  /* MCU Configuration--------------------------------------------------------*/

  /* Reset of all peripherals, Initializes the Flash interface and the Systick. */
  HAL_Init();

  /* Configure the system clock */
  SystemClock_Config();

  /* Initialize all configured peripherals */
  MX_GPIO_Init();
  MX_TIM2_Init();
  MX_TIM3_Init();
  MX_DMA_Init();
  MX_ADC1_Init();
  MX_TIM4_Init();
  MX_TIM1_Init();
  /* USER CODE BEGIN 2 */

  // Create SPWM Array (DO NOT CHANGE)

  for (int i=0; i<(sinDivision/2); i++)
  {
	  temp = sin((i+0.5) * 2 * M_PI / sinDivision) * period;
	  lookUp[i] = (int)(temp+0.5);
  }

  htim2.Instance->CCR2 = 0;
  htim2.Instance->CCR3 = 0;
  HAL_TIM_Base_Start_IT(&htim2);
  HAL_TIM_PWM_Start(&htim2,TIM_CHANNEL_2);
  HAL_TIM_PWM_Start(&htim2,TIM_CHANNEL_3);

  HAL_TIM_PWM_Start(&htim1, TIM_CHANNEL_1);
  HAL_TIM_PWM_Start(&htim1, TIM_CHANNEL_2);
  HAL_TIM_PWM_Start(&htim1, TIM_CHANNEL_3);

  HAL_TIM_PWM_Start(&htim3, TIM_CHANNEL_1);

  HAL_TIM_PWM_Start(&htim4, TIM_CHANNEL_1);

  // Set all PWM to Zero
  TIM1->CCR1 = nowTrafoSwitchingValue;
  TIM1->CCR2 = nowIsolatedBuckValue;
  TIM1->CCR3 = maxTrafoSwitchingValue;

  TIM3->CCR1 = nowBoostValue;

  TIM4->CCR1 = nowInputGateValue;



  /* USER CODE END 2 */

  /* Infinite loop */
  /* USER CODE BEGIN WHILE */
  while (1)
  {
	  // increase led counter
	  ledCounter += 1;

	  // Read Sensor
	  HAL_ADC_Start_DMA(&hadc1, adcReading, 6);

	  adcValue0 = adcReading[0];
	  adcValue1 = adcReading[1];
	  adcValue2 = adcReading[2];
	  adcValue3 = adcReading[3];
	  adcValue4 = adcReading[4];
	  adcValue5 = adcReading[5];

	  batteryVoltage = ((adcValue0 / 4096.0) * 3.3) * 21 ;
	  inputVoltage = ((adcValue1 / 4096.0) * 3.3) * 21 ;
	  ctVoltage = ((adcValue3 / 4096.0) * 3.3) * 21 ;

	  temperature1 = ((adcValue4 / 4096) * 3.3) * 100;
	  temperature2 = ((adcValue5 / 4096) * 3.3) * 100;

	  /*
	  // Take Action based on Battery Voltage
	  // inverter mode when voltage > 50V
	  if (batteryVoltage > 50)
	  {
		  inverterMode = 1;
	  }

	  // charging mode when voltage < 39V
	  if (batteryVoltage < 39)
	  {
		  inverterMode = 0;
	  }
	  */

	  // Decide Mode to be used
	  inverterMode = 1;

	  // If Charging Mode is used
	  if (inverterMode == 0)
	  {
		  // Turn off inverter mode mosfet
		  HAL_GPIO_WritePin(GPIOB, FORWARD_Pin, GPIO_PIN_RESET);

		  // Stop Input Voltage
		  nowInputGateValue = 0;
		  TIM4->CCR1 = nowInputGateValue;

		  // Stop isolated buck converter
		  nowIsolatedBuckValue = 0;
		  TIM1->CCR2 = nowIsolatedBuckValue;


		  // Run Boost Converter
		  nowBoostValue = maxBoostValue * 30.0 / 100.0;
		  TIM3->CCR1 = nowBoostValue;


		  // Activate charging mode mosfet
		  // if ctVoltage become zero
		  // to prevent short circuit
		  if (ctVoltage == 0)
		  {
			  HAL_GPIO_WritePin(GPIOB, REVERSE_Pin, GPIO_PIN_SET);
			  HAL_Delay(1);
		  }


		  if (ledCounter >= 5000)
		  {
			  HAL_GPIO_TogglePin(GPIOC, GPIO_PIN_13);
			  ledCounter = 0;
		  }
	  }

	  // If Inverter Mode is used
	  if (inverterMode == 1)
	  {
		  // Turn off charging mode mosfet
		  HAL_GPIO_WritePin(GPIOB, REVERSE_Pin, GPIO_PIN_RESET);

		  // Stop Boost Converter
		  nowBoostValue = 0;
		  TIM3->CCR1 = nowBoostValue;

		  // Run Isolated Buck Converter at 50% duty cycle
		  nowIsolatedBuckValue = maxIsolatedBuckValue / 2;
		  TIM1->CCR2 = nowIsolatedBuckValue;

		  // Run Switching for Trafo at 50% duty cycle
		  nowTrafoSwitchingValue = maxTrafoSwitchingValue / 2;
		  TIM1->CCR1 = nowTrafoSwitchingValue;
		  TIM1->CCR3 = nowTrafoSwitchingValue;

		  // Activate Forward Mosfet
		  HAL_GPIO_WritePin(GPIOB, FORWARD_Pin, GPIO_PIN_SET);
		  //HAL_GPIO_WritePin(GPIOB, FORWARD_Pin, GPIO_PIN_RESET);

		  // Conditioning input voltage
		  // set to x Volt
		  if(batteryVoltage < 10)
		  {
			  nowInputGateValue = nowInputGateValue+1;
		  }
		  if(batteryVoltage > 10)
		  {
			  nowInputGateValue = nowInputGateValue-1;
		  }
		  if(batteryVoltage == 10)
		  {
			  nowInputGateValue = nowInputGateValue;
		  }
		  //TIM4->CCR1 = nowInputGateValue;
		  TIM4->CCR1 = maxInputGateValue/2;

		  if (ledCounter >= 20000)
		  {
			  HAL_GPIO_TogglePin(GPIOC, GPIO_PIN_13);
			  ledCounter = 0;
		  }
	  }
    /* USER CODE END WHILE */

    /* USER CODE BEGIN 3 */
  }
  /* USER CODE END 3 */
}

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
/* USER CODE BEGIN 4 */
void HAL_TIM_PeriodElapsedCallback(TIM_HandleTypeDef *htim)
{
	static int num=0;
	static int delay1=0;
	static int toggling=0;
	static int delay2=0;

	if(delay1 == 1)
	{
		delay2++;
		if(delay2>=5)
		{
			delay2=0;
			delay1=0;
		}
	}
	else if(num>= sinDivision/2)
	{
		num = 0;
		delay1++;
		htim2.Instance->CCR2 = 0;
		htim2.Instance->CCR3 = 0;
		if(toggling == 0)
		{
			toggling++;
		}
		else
		{
			toggling = 0;
		}
	}
	if(toggling == 0 && delay1 !=1)
	{
		htim2.Instance->CCR2 = lookUp[num];
		htim2.Instance->CCR3 = 0;
	}
	else if(toggling == 1 && delay1 !=1)
	{
		htim2.Instance->CCR2 = 0;
		htim2.Instance->CCR3 = lookUp[num];
	}

	num++;
}

/* USER CODE END 4 */
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


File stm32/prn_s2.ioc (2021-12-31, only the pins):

Mcu.UserName=STM32F103C8Tx
PA0-WKUP.Signal=ADCx_IN0
PA1.Signal=S_TIM2_CH2
PA10.Signal=S_TIM1_CH3
PA13.Signal=SYS_JTMS-SWDIO
PA14.Signal=SYS_JTCK-SWCLK
PA2.Signal=S_TIM2_CH3
PA3.Signal=ADCx_IN3
PA4.Signal=ADCx_IN4
PA5.Signal=ADCx_IN5
PA6.Signal=S_TIM3_CH1
PA8.Signal=S_TIM1_CH1
PA9.Signal=S_TIM1_CH2
PB0.Signal=ADCx_IN8
PB1.Signal=ADCx_IN9
PB3.GPIO_Label=REVERSE
PB3.Signal=GPIO_Output
PB4.GPIO_Label=FORWARD
PB4.Signal=GPIO_Output
PB6.Signal=S_TIM4_CH1
PC13-TAMPER-RTC.Signal=GPIO_Output
PD0-OSC_IN.Signal=RCC_OSC_IN
PD1-OSC_OUT.Signal=RCC_OSC_OUT

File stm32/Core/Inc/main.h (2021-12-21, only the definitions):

#define REVERSE_Pin GPIO_PIN_3
#define REVERSE_GPIO_Port GPIOB
#define FORWARD_Pin GPIO_PIN_4
#define FORWARD_GPIO_Port GPIOB

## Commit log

2021-12-31 pcb files
    [PRN_S2_v1.0.brd, PRN_S2_v1.0.sch]
2022-01-03 adc and timer

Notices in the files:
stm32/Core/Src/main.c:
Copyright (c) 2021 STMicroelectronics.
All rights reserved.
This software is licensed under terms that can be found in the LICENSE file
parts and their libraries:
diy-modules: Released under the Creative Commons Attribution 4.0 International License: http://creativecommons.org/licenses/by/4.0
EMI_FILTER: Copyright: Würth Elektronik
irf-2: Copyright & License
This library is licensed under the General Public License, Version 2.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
